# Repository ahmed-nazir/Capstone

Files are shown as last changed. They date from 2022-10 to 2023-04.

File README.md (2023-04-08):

# Formulate

Developer Names: Ahmed Nazir, Stephen Oh, Muhanad Sada, Tioluwalayomi Babayeju

Project Start Date: September 12th 2022

## Description

Competitive engineering extracurricular activities at the University level revolves around the design, build, test, learn (DBTL) cycle. In teams that have not yet reached maturity in completing high quality and timely DBTL cycles, the design/building phases are over-prioritized, leaving the testing/learning phases under-resourced.
Most teams struggling to achieve timely DBTL cycles compete in deeply technical applications of engineering. Problematically, deeply technical applications demand significant amounts of time into the design/build phase of a competition year to create a working prototype.

Our capstone group recognizes the challenge teams face with the under-allocation of resources for testing, and seek to produce a solution that reduces the time to obtain and store quality testing data and extract value from the raw data they collect.

## Summary

https://user-images.githubusercontent.com/31586040/229315702-d01e6bb1-cf8b-4a10-88e6-f17f51ce0d29.mp4

## Device Hardware

https://user-images.githubusercontent.com/31586040/229315661-3c283bd7-a839-4dc5-8188-416b881f1b61.mp4

### Exploded View

Chassis Assembly Exploded View

### PCB
PCB1 

## Folder Structure

The folders and files for this project are as follows:

- docs - Documentation for the project
- refs - Reference material used for the project, including papers
- src - Source code
- test - Testing

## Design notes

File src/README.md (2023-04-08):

# Formulate Source Code

The folders and files for this project are as follows:
- Chassis
- Database
- Desktop Application
- Electrical
- Formulate Application
  - Final Portable Application
- Power Bi

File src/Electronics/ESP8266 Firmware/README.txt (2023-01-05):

The board used in our Formulate project is the ESP8266 12E (NodeMCU 1.0)

- This process is to be done to reset the board to its original state if firmware becomes corrupt

////FLASH FIRMWARE/////

Required:
- NodeMCU Firmware Flasher (https://github.com/nodemcu/nodemcu-flasher)
- Firmware is from (https://github.com/espressif/ESP8266_NONOS_SDK/releases) the version we used was ESP8266_NONOS_SDK v2.0.0

Steps:
- Ensure nothing is connected to the NodeMCU and connect via micro USB

- Go to the advanced tab and set the parameters as follows
	- Baudrate: 230400
	- Flash size: 4MBytes
	- Flash speed: 40MHz
	- SPI Mode: QIO

- Go to the config tab and flash the following files
	- boot_v1.6.bin			@ 0x00000
	- user1.1024.new.2.bin 		@ 0x01000
	- esp_init_data_default.bin	@ 0x3FC000
	- blank.bin				@ 0x7E000

- Open the Arduino IDE and open the serial monitor with the correct COM port and set the baudrate to 115200 and select Newline and CR
	- Send an "AT" command, if it returns "OK" firmware is flashed successfully

	- Set the baudrate to 9600 permanently with "AT+UART_DEF=9600,8,1,0,0"
	
	- Change baudrate to 9600 on the serial monitor and test the "AT" command again after clicking the reset button on the NodeMCU

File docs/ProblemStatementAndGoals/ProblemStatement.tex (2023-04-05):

\documentclass[12pt,titlepage]{article}

\usepackage{tabularx}
\usepackage{booktabs}
\usepackage{float}
\usepackage{fullpage}
\usepackage{longtable}

\title{\huge Problem Statement and Goals\\\progname}

\author{\authname}

\date{\today}

\input{../Comments}
\input{../Common}

\begin{document}

\maketitle
\newpage

\begin{table}[hp]
\caption{Revision History} \label{TblRevisionHistory}
\begin{tabularx}{\textwidth}{llX}
\toprule
\textbf{Date} & \textbf{Developer(s)} & \textbf{Change}\\
\midrule
09/24/22 & Ahmed Nazir & Goals, Stretch Goals\\
09/25/22 & Stephen Oh & Problem Statement, Input/Output, Stakeholders\\
04/03/23 & Stephen, Ahmed & Final Revision\\
04/05/23 & All & Revision 1\\
\bottomrule
\end{tabularx}
\end{table}

\newpage
\tableofcontents
\listoftables

\newpage
\section{Problem Statement}

\wss{You should check your problem statement with the
\href{https://github.com/smiths/capTemplate/blob/main/docs/Checklists/ProbState-Checklist.pdf}
{problem statement checklist}.}
\wss{You can change the section headings, as long as you include the required information.}
%Stephen updated this section, Sunday afternoon
Competitive engineering extracurricular activities at the University level revolve around the design, build,
test, learn (DBTL) cycle. In teams that have not yet reached maturity in completing high quality and
timely DBTL cycles, inexperience in the testing phase causes undesirable inefficiencies in testing
workflow such as unstandardized testing styles, collection of data, and storage of data. Such
inefficiencies also affect team workflow performance at the macro scale due to a reduced ability to
clearly view aggregate trends from unstandardized testing workflows. 

\subsection{Problem}

Our capstone group recognizes the challenge teams face with the under-allocation of resources for testing, and seek to produce a solution that reduces the time to obtain and store quality testing data and extract value from the raw data they collect. \\ 

\subsection{Inputs and Outputs}

\wss{Characterize the problem in terms of ``high level'' inputs and outputs.  
Use abstraction so that you can avoid details.}
%Stephen updated this section, Sunday afternoon

The solution will collect raw data as input and output Key Performance Indicators (KPI) statistics generated from test data. \\

Raw data input to the system will normally be aggregated upon completion of the test. The system will then communicate the contents of the aggregated data to a computing device. Users will have the opportunity to provide input on the raw data collected before saving it to a database. This input should allow the user to add contextual details to the test data to describe what the test is doing. The user will then submit the data to a database with additional information to specify key details of the test. A visualization platform will then allow users to view generated KPI statistics on the test data stored in the database. \\

Inputs: \\
A. User login to link test data to team member. \\
B. Raw data collected by testing sensors. \\
C. Communication method mode selection between wired versus wireless transfer of raw test data between the hardware and the desktop application. \\
%C. User modifications of raw test data file to maintain consistency in data through data point modifications. \\
D. User notes and picture on test data file to specify contextual details of test data collected. 

\newpage
%E. Data processing mode select between generating KPI metrics in real time, live data collection, versus generating KPI metrics in post with data from a complete test. \\

Outputs: \\
A. Tabular view of most recently collected test data over the test duration time on user application upon test completion. \\
B. Test data storage in the database. \\
C. Graphical view on visualization platform of test data over time. \\
D. Tabular view on visualization platform of Key Performance Indicators. \\
E. Visual indication from electrical hardware conveying device on/off state and wireless connection state. 
%C. Historical trends of related test Key Performance Indicator results. \\
%D. Testing trends across sub-teams. \newpage

\subsection{Stakeholders}

Formula Electric teams exemplify a highly technical, extra-curricular engineering team at the University level. On a yearly basis, these teams participate in competitions organized by a governing body, Formula SAE, who judge the quality and effectiveness of engineering ideas, designs, fabrications, and tests applied on a team's vehicle. \\

Specifically, ideal candidates who can benefit from our capstone will be Formula Electric teams with 0-4 years of competition experience. Teams without four years of experience are ideal because they typically cannot finish comprehensive tests to validate sub-team designs and overall vehicle design in a competition year. \\

As a result, our primary stakeholder will be McMaster's Formula Electric team because the team has 3 years of competition experience and faces difficulty validating all aspects of the vehicle through comprehensive testing. \\

\subsection{Environment}
The editing environment for the Arduino will be the Arduino Software IDE which has a text editor for writing code, a serial monitor to receive messages, a toolbar for common functions, and multiple menus for various applications. In this environment, the Arduino can be programmed to communicate with the user interface application running in parallel. \\

Our main environment for software programming will be Visual Studio Code. This is where we will write our code to run functions that will program our Arduino and other functions that we will need. It will also be used to write SQL code which can continually receive data from our hardware components.

\wss{Hardware and software}
\newpage
\section{Goals}
    \begin{longtable}{|p{6cm}|p{10cm}|}
    \hline
    \multicolumn{1}{|c|}{\textbf{Goals}} & \multicolumn{1}{c|}{\textbf{Explanation}} 
    \\ \hline
    Electrical Hardware capable of collecting sensor test data
    & The electrical hardware should be able to obtain and record sensor test data for the main measurements desired. The hardware should be able to collect vibration, shock, temperature and humidity measurements
    \newline                                
    \\ \hline
    Wired and wireless hardware to laptop connection
    & The hardware can support user selection between connection via a wired connection between the hardware to a laptop running the application or a wireless connection between the hardware and the laptop
    \newline                                
    \\ \hline
    Wireless connection failsafe test data storage
    & Electrical Hardware can save a complete data set from the previous test in a local memory module
    \newline                                
    \\ \hline
    Electrical connection mechanism between the electrical hardware and sensor conductors
    & The electrical hardware allows the user to fasten and unfasten sensor conductors to support varying test setups
    \newline                                
    \\ \hline
    A user interface which interacts and submits the data                                 
    & A modern GUI that is intuitive and easy to use, which should be able to communicate with our hardware to receive the measurements from the sensor. The GUI should have two modes, the first showing the live data as it comes from the device. The second mode should allow for the user to preview the data from the test, and extract certain important parts before sending it into the database  
    \newline                                
    \\ \hline
    A record of the historical data should be organized                                
    & To keep testing consistent and comparable, all previous test data should be organized into a database which cannot be edited to prevent users from tampering with test results. Historical data will allow Formula teams to be able to see how certain modifications to their design can improve or hurt motor test results. 
    \newline                                
    \\ \hline
    The final product should have a website which displays the data in a useful manner                                
    & Once all the  tests are sent to the database, we will have a website which shows all the major test information in a data analytics platform to quickly and easily see if the vehicle is hitting targets  
    \newline                              
    \\ \hline
    Setup of our device should be quick and easy                               
    & When a user would like to conduct a test our hardware should be hassle free and not add too much time to the overall setup
    \newline                            
    \\ \hline
    \caption{Goals}
    \end{longtable}

\section{Stretch Goals}
    \begin{longtable}{|p{6cm}|p{10cm}|}
        
        \hline
        \multicolumn{1}{|c|}{\textbf{Goals}} & \multicolumn{1}{c|}{\textbf{Explanation}} 
        \\ \hline
        Custom Website
        &  Creating a GUI from scratch would make the website more customizable to our particular application in terms of UI/UX   
        \newline                              
        \\ \hline
        Critical Alert                              
        & The critical alert feature would display to the user on both the App GUI and on the screen that the current test being performed is exceeding the operating conditions of the device being tested. This will bring attention to the user and they will be able to stop the test
        \newline
        \\ \hline
        Predictive Data                              
        & Since all the testing data and test conditions are being stored in our database, we could create a machine learning model which will be able to tell us how the motor will perform under certain conditions                         
        \newline       
        \\ \hline
        Security                              
        & When data is being transmitted from our hardware device to our computer, the data should be encrypted and secure to prevent tampering with data
        \newline                           
        \\ 
        \hline
        \caption{Stretch Goals}
    \end{longtable}

\end{document}

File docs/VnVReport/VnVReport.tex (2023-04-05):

\documentclass[12pt, titlepage]{article}

\usepackage{booktabs}
\usepackage{tabularx}
\usepackage{hyperref}

\usepackage{fullpage}
\usepackage[round]{natbib}
\usepackage{multirow}
\usepackage{booktabs}
\usepackage{tabularx}
\usepackage{graphicx}
\usepackage{float}
\usepackage{hyperref}
\usepackage{colortbl}
\usepackage{longtable}
\usepackage[table]{xcolor} 
\usepackage{longtable}
\hypersetup{
    colorlinks,
    citecolor=black,
    filecolor=black,
    linkcolor=red,
    urlcolor=blue
}
\usepackage[round]{natbib}

\input{../Comments}
\input{../Common}

\begin{document}

\title{\huge Verification and Validation Report \\ \progname} 
\author{\authname}
\date{\today}
	
\maketitle

\pagenumbering{roman}

\section{Revision History}

\begin{tabularx}{\textwidth}{p{3cm}p{2cm}X}
\toprule {\bf Date} & {\bf Version} & {\bf Notes}\\
\midrule
March 3, 2023 & 1.0 & Final Revision\\
\bottomrule
\end{tabularx}

~\newpage

\section{Symbols, Abbreviations and Acronyms}

\renewcommand{\arraystretch}{1.2}
\begin{tabular}{l l} 
  \toprule		
  \textbf{symbol} & \textbf{description}\\
  \midrule 
  \progname & Mechatronics Engineering Capstone Course\\
  UART & Universal Asynchronous Receiver-Transmitter\\
  SPI & Serial Peripheral Interface\\
  I2C & Inter-Integrated Circuit\\
  USB & Universal Serial Bus\\
  TCP & Transmission Control Protocol\\
  IP & Internet Protocol\\
  SPDT & Single pole, double throw \\
  TCP/IP & Transmission Control Protocol / Internet Protocol \\
  SOC & Software On Chip \\
  SPST & Single pole, single throw \\
  TX & Transmit \\
  RX & Recieve \\
  USB & Universal Serial Bus \\
  LED & Light-emitting diode \\
  GB & GigaByte \\
  SD & Secure Digital \\
  PCB & Printed Circuit Board \\
  \bottomrule
\end{tabular}\\

\wss{symbols, abbreviations or acronyms -- you can reference the SRS tables if needed}

\newpage

\tableofcontents

\listoftables %if appropriate

\listoffigures %if appropriate

\newpage

\pagenumbering{arabic}

\section{Functional Requirements Evaluation}
\subsection{Sensor Verification}
%sensor validation: Stephen
\begin{table}[H]
  \begin{tabular}{| p{0.15\textwidth} | p{0.10\textwidth}| p{0.28\textwidth}| p{0.28\textwidth}| p{0.09\textwidth}|}
    \hline
    \rowcolor[gray]{0.9}
    Test Number & Type & Input & Output & Result\\
    \hline
    ST-SV 1 & Manual & Room at a constant 25 $^{\circ}$C ambient & Constant 25.4 $^{\circ}$C reading from temperature sensor & Pass \\
    \hline
    ST-SV 2 & Manual & Room at constant 40\% humidity $^{\circ}$C & Constant 43\% reading from humidity sensor & Pass \\
    \hline
    ST-SV 3 & Manual & 4 seperate phonecalls with accelerometer measuring haptic feedback & Maximum error between acceleration profiles of phone calls within 0.2 meters per second squared & Pass  \\
    \hline
  \end{tabular}
  \caption{Sensor Validation}
  \end{table}

%device telemetry: Ahmed
\subsection{Device Telemetry}
\begin{table}[H]
  \begin{tabular}{| p{0.15\textwidth} | p{0.10\textwidth}| p{0.28\textwidth}| p{0.28\textwidth}| p{0.09\textwidth}|}
    \hline
    \rowcolor[gray]{0.9}
    Test Number & Type & Input & Output & Result\\
    \hline
    ST-DT 1 & Manual & The device is connected via Wi-Fi and the start button is pressed on the GUI & The device beings to send and display the sensor data in the GUI & Pass \\
    \hline
    ST-DT 2 & Manual & The device is connected via Wi-Fi and the start button is pressed multiple times in the GUI & The start button greys out not allowing the user to press it multiple times and the sensors still send data to the GUI & Pass \\
    \hline
    ST-DT 3 & Manual & The device is connected via Wi-Fi and the stop button is pressed on the GUI & The device stops sending data to the GUI & Pass  \\
    \hline
    ST-DT 4 & Manual & The device is connected via Wi-Fi and the stop button is pressed multiple times in the GUI & The stop button greys out not allowing the user to press it multiple times and the device does not send data & Pass  \\
    \hline
  \end{tabular}
  \caption{Device Telemetry}
  \end{table}

%device hardware: Stephen
\subsection{Device Hardware}
\begin{table}[H]
  \begin{tabular}{| p{0.15\textwidth} | p{0.10\textwidth}| p{0.28\textwidth}| p{0.28\textwidth}| p{0.09\textwidth}|}
    \hline
    \rowcolor[gray]{0.9}
    Test Number & Type & Input & Output & Result\\
    \hline
    ST-DH 1 & Manual & Temperature sensor male end JST connector unconnected to the device's female JST connector & Device measured the room's ambient temperature at 23.4 $^{\circ}$C & Pass \\
    \hline
    ST-DH 2 & Manual & Device collecting sensor data at low battery charge & Device unoperational upon battery depletion and halted sensor data collection & Fail \\
    \hline
    ST-DH 3 & Manual & 5 kg dumbbell placed on each corner of the device chassis & No plastic failure in device chassis & Pass  \\
    \hline
    ST-DH 4 & Manual & A member on the formula electric team was given a cross screwdriver, M4 screw, the device, and DIN rail & The formula electric team member mounted the device in 40 seconds & Pass  \\
    \hline
%REMEMBER TO DELETE ST-DH5 FROM VNVPLAN, WE DO NOT NEED THIS TEST AS WE DO NOT HAVE A SCREEN OR DEVICE STATUS MEASUREMENTS
  \end{tabular}
  \caption{Device Hardware}
  \end{table} 

  ST-DH3 failed the functional test case. The team estimated the time required to design and integrate a rechargeable battery subsystem within the project's timeline was 1.5 weeks and decided the effort was not worthwhile relative to other project objectives. As a result, the failure of this test case lead the expected operation at low battery to be adjusted. Users are now expected to replace the battery on a regular schedule to prevent a failure in test integrity due to charge depletion. \\

\newpage
%desktop app: Mo
\subsection{Desktop Application}
ST-DA3 and ST-DA4 are included in unit testing, refer to section 5.3 for further details.
\begin{table}[H]
\begin{tabular}{| p{0.15\textwidth} | p{0.10\textwidth}| p{0.28\textwidth}| p{0.28\textwidth}| p{0.09\textwidth}|}
  \hline
  \rowcolor[gray]{0.9}
  Test Number & Input & Expected Output & Actual Output & Result\\
  \hline
  ST-DA5 & User clicks on 'Start Test' button in 'View Test' page & Live data start to populate a table in the UI & Live measurement data is displayed in a table in the UI & pass \\
  \hline
\end{tabular}
\caption{Desktop Application}
\end{table}

%data analytics: Tio
\subsection{Data Dashboard}
\begin{table}[H]
  \begin{tabular}{| p{0.15\textwidth} | p{0.10\textwidth}| p{0.28\textwidth}| p{0.28\textwidth}| p{0.09\textwidth}|}
    \hline
    \rowcolor[gray]{0.9}
    Test Number & Type & Input & Output & Result\\
    \hline
    ST-DD 1 & Manual & The user was given a username and password to login into Power BI & The user was able to view all the different data that was being recorded during the test and previous tests as well & Pass\\
    \hline
    ST-DD 2 & Manual & The user was given a fake username and password that is not authorized to view the data & The user was not able to view the Power BI dataset that was created to view all the different test data & Pass\\
    \hline
  \end{tabular}
  \caption{Data Analytics}
  \end{table} 

We created our Data Dashboard through a visualization tool called Power Bi and tested it to see if we were able to connect to the database which contained all our data values. We able to get all the values of our data from the database since Power Bi has a method that can connect to database that authorized users are allowed to connect to. Since this was the case we were able to pass this this requirement for our the data analytics.

%database: Mo
\subsection{Database}
\begin{table}[H]
\begin{tabular}{| p{0.15\textwidth} | p{0.10\textwidth}| p{0.28\textwidth}| p{0.28\textwidth}| p{0.09\textwidth}|}
  \hline
  \rowcolor[gray]{0.9}
  Test Number & Input & Expected Output & Actual Output & Result\\
  \hline
  ST-D1 & User clicks on 'Submit' button in 'Submit Test' page consecutively in a short period of time & UI displays error message 'Too many submissions' in red & 'Too many submissions' is displayed in red & pass \\
  \hline
\end{tabular}
\caption{Database}
\end{table}

\newpage

\section{Nonfunctional Requirements Evaluation}
\subsection{Usability}
%Stephen
%Need a graph (that we generate) that supports data

  \begin{longtable}{| p{0.15\textwidth} | p{0.10\textwidth}| p{0.28\textwidth}| p{0.28\textwidth}| p{0.09\textwidth}|}
    \hline
    \rowcolor[gray]{0.9}
    Test Number & Type & Input & Output & Result\\
    \hline
    ST-U 1-A & Manual & User connects a thermistor to device, begins collecting sensor test data and gathers data for 1 minute, completes collecting sensor test data, adds remarks to the test, and submits test data to database & User completed the overall process in 3 minutes 43 seconds and rated the sensor mount and measuring procedure a 5. All other categories were given a 4 & Pass \\
    \hline
    ST-U 1-B & Manual & User adjusts Arduino code for a fluid flow rate sensor, connects the sensor to the device, begins collecting sensor test data and gathers data for 1 minute, completes collecting sensor test data, adds remarks to the test, and submits test data to database & User completed the process in 49 minutes 15 seconds and rated the overall experience a 2. The sensor mount and measuring procedure categories were given a 5. All other cattegories were given a 4 & Fail \\
    \hline
    ST-U 2-A & Manual & Device collecting sensor data with wired connection to a laptop running the python application & Python application GUI displayed at minimal latency. Less than 1 second latency for changes in sensor measurements to display on GUI. Users selected Formulate for all 4 categories & Pass \\
    \hline
    ST-U 2-B & Manual & Device collecting sensor data with wireless connection to a laptop running the python application & Python application GUI displayed at minimal latency. Less than 1 second latency for changes in sensor measurements to display on GUI. Users selected Formulate for all 4 categories& Pass \\
    \hline

    ST-U 3-A & Manual & Device connection to application is broken. User submits previous test data held on the micro-SD module to the database & Test data submits and test contents can be viewed on dashboard. An average score of 4 was provided & Pass \\
    \hline
    ST-U 3-B & Manual & Application connection to database is broken. User can connect a temperature sensor, start a test, and stop a test & Device recognizes sensor, starts test, and stops test. An average score of 4 was provided & Pass  \\
    \hline
    \caption{Usability}

  \end{longtable}

  \begin{figure}[htbp!]
    \begin{center}
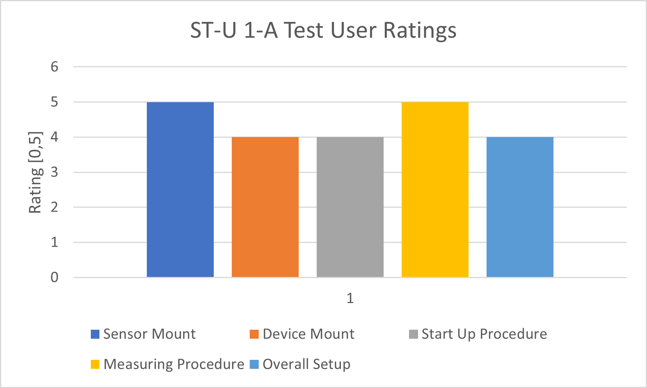
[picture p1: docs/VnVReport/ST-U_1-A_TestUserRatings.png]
    
    \caption{ST-U 1-A Test User Ratings}
    \end{center}
    \end{figure}

  \begin{figure}[htbp!]
    \begin{center}
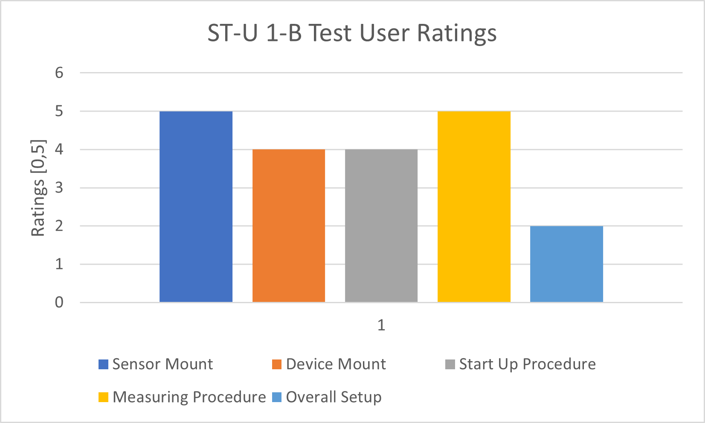
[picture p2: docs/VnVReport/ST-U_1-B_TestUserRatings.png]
    
    \caption{ST-U 1-B Test User Ratings}
    \end{center}
    \end{figure}
\newpage
  ST-U 1-B failed the usability test case. The difference between ST-U 1-B and ST-U 1-A was the user requirement to adjust and write the Arduino code for a sensor not previously used with the device. Notably, the user experienced difficulty and was intimidated with adjusting existing code to integrate a new sensor. This effect was shown in both the increased time to complete the overall process and the decreased rating in the overall test experience category. As a result, the project will have an approach whereby the user should only interact with the graphical user interface to reduce the user's feelings of complexity and intimidation when integrating a new sensor. The goal is to abstract the adjustments in the backend when implementing a new sensor by having the user interact only with the GUI and following guided steps in plain English to fill in the required information to integrate a new sensor. \\

\subsection{Performance}
%Tio
\begin{table}[H]
  \begin{tabular}{| p{0.15\textwidth} | p{0.10\textwidth}| p{0.28\textwidth}| p{0.28\textwidth}| p{0.09\textwidth}|}
    \hline
    \rowcolor[gray]{0.9}
    Test Number & Type & Input & Output & Result\\
    \hline
    ST-P 1 & Dynamic, Manual & The device will be mounted and be tested in various conditions & The device was operational and stayed physcially intact after being tested in various conditions & Pass\\
    \hline
    ST-P 2 & Dynamic, Manual & The device will be operating and collecting data from a test and streaming the results to our desktop application & The latency between the collecting of data and the streaming of it remained below 10 seconds & Pass\\
    \hline
    ST-P 3 & Dynamic, Manual & The device will be operating with one or more of the connections to either the device, application and or database & The user is still able to obtain the test results of the current test no matter which connections are missing on the overall connection & Pass\\
    \hline
  \end{tabular}
  \caption{Performance}
  \end{table}

  \begin{figure}[H]
    \begin{center}
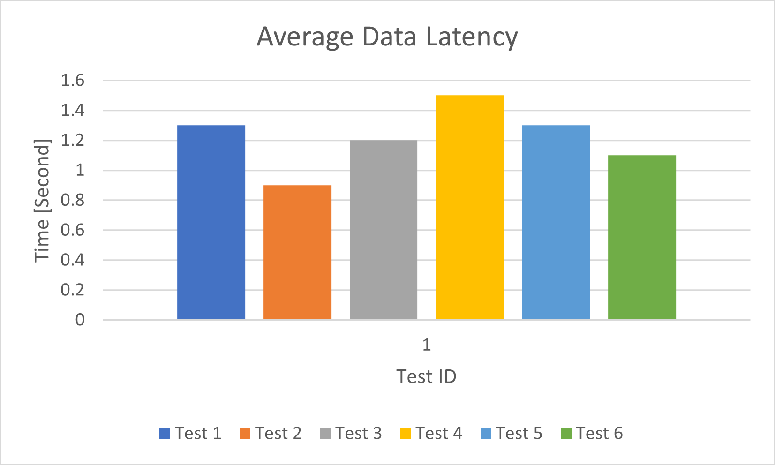
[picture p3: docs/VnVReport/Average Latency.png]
    
    \caption{Average Latency Results of Each Test}
    \end{center}
    \end{figure}

\subsection{Security}
%Tio
\begin{table}[H]
  \begin{tabular}{| p{0.15\textwidth} | p{0.10\textwidth}| p{0.28\textwidth}| p{0.28\textwidth}| p{0.09\textwidth}|}
    \hline
    \rowcolor[gray]{0.9}
    Test Number & Type & Input & Output & Result\\
    \hline
    ST-S 1 & Dynamic, Manual & User will receive numerous usernames and passwords and attempt to access the database & The database was only accessible using the correct username, password and only with specific ip addresses that have been accepted & Pass\\
    \hline
    ST-S 2 & Dynamic, Manual & Multiple fake data points were attempted to be added to the database & The database remained the same even after the attempted modification ensuring that only authorized were allowed to modify the database & Pass\\
    \hline
  \end{tabular}
  \caption{Security}
  \end{table}

\newpage
\section{Unit Testing}
\subsection{Module - ui\_functions.py}
%Desktop App Code: Mo
%Arduino Code: Ahmed
connect\_wireless(self) - Tested by clicking connect button on wireless page
\begin{table}[H]
  \begin{tabular}{| p{0.1\textwidth} | p{0.15\textwidth}| p{0.28\textwidth}| p{0.28\textwidth}| p{0.09\textwidth}|}
    \hline
    \rowcolor[gray]{0.9}
    Test No. & Input & Expected Output & Actual Output & Result\\
    \hline
    U1 & Connected to Formulate Wi-Fi & The application should connect to the device and display that it is connected & The application shows that the device is connected & Pass \\
    \hline
    U2 & Not Connected to Formulate Wi-Fi  & The application should display a pop up error indicating to the user that they need to connect to the Formulate Wi-Fi & A popup is displayed to the user to indicate they need to connect to Wi-Fi & Pass \\
    \hline
    U3 & -Connected to Formulate Wi-Fi -Device is connected via Serial (Wired) & The application should disconnect from serial and follow U1 & The application disconnects from serial and follows U1 & Pass \\
    \hline
  \end{tabular}
  \caption{Unit Test - connect\_wireless(self)}
  \end{table}

disconnect\_wireless(self) - Tested by clicking disconnect button on wireless page
\begin{table}[H]
  \begin{tabular}{| p{0.1\textwidth} | p{0.15\textwidth}| p{0.28\textwidth}| p{0.28\textwidth}| p{0.09\textwidth}|}
    \hline
    \rowcolor[gray]{0.9}
    Test No. & Input & Expected Output & Actual Output & Result\\
    \hline
    U4 & -Connected to Formulate Wi-Fi -The disconnect button is clicked & The application should disconnect from the board and display that it is disconnected & The application disconnects from board and shows its disconnected & Pass \\
    \hline
    U5 & Not Connected to Formulate Wi-Fi  & The application should not display the disconnect button on the connectivity widget & The application does not display the disconnect button & Pass \\
    \hline
  \end{tabular}
  \caption{Unit Test - disconnect\_wireless(self)}
  \end{table}

  connect\_wired(self) - Tested by clicking connect button on wired page
  \begin{table}[H]
    \begin{tabular}{| p{0.1\textwidth} | p{0.15\textwidth}| p{0.28\textwidth}| p{0.28\textwidth}| p{0.09\textwidth}|}
      \hline
      \rowcolor[gray]{0.9}
      Test No. & Input & Expected Output & Actual Output & Result\\
      \hline
      U6 & Connected to PC via USB and the correct COM port is selected in the Wire connectivity widget & The application should connect to the device and display that it is connected & The application shows that the device is connected & Pass \\
      \hline
      U7 & Not Connected to PC via wire  & The application should not display any COM port in the widget & The wired drop down is empty and shows no COM port & Pass \\
      \hline
      U8 & -Connected to PC via USB and the correct COM port is selected in the Wire connectivity widget -Device is connected via WiFi & The application should disconnect from WiFi and follow U6 & The application disconnects from WiFi and follows U6 & Pass \\
      \hline
    \end{tabular}
    \caption{Unit Test - connect\_wired(self)}
    \end{table}
  
  disconnect\_wired(self) - Tested by clicking disconnect button on wired page
  \begin{table}[H]
    \begin{tabular}{| p{0.1\textwidth} | p{0.15\textwidth}| p{0.28\textwidth}| p{0.28\textwidth}| p{0.09\textwidth}|}
      \hline
      \rowcolor[gray]{0.9}
      Test No. & Input & Expected Output & Actual Output & Result\\
      \hline
      U9 & -Connected via wired -The disconnect button is clicked & The application should disconnect from the board and display that it is disconnected & The application disconnects from board and shows its disconnected & Pass \\
      \hline
    \end{tabular}
    \caption{Unit Test - disconnect\_wired(self)}
    \end{table}
\newpage

  ping(self) - Tested by clicking connect button
  \begin{table}[H]
    \begin{tabular}{| p{0.1\textwidth} | p{0.15\textwidth}| p{0.28\textwidth}| p{0.28\textwidth}| p{0.09\textwidth}|}
      \hline
      \rowcolor[gray]{0.9}
      Test No. & Input & Expected Output & Actual Output & Result\\
      \hline
      U10 & Connected via WiFi & The application should read which sensors are flashed on the board and display them & The application gets which sensors are flashed and displays them & Pass \\
      \hline
      U11 & Connected via wired & The application should read which sensors are flashed on the board and display them & The application gets which sensors are flashed and displays them & Pass \\
      \hline
    \end{tabular}
    \caption{Unit Test - ping(self)}
    \end{table}

  startTest(self) - Tested by clicking startTest button
  \begin{table}[H]
    \begin{tabular}{| p{0.1\textwidth} | p{0.15\textwidth}| p{0.28\textwidth}| p{0.28\textwidth}| p{0.09\textwidth}|}
      \hline
      \rowcolor[gray]{0.9}
      Test No. & Input & Expected Output & Actual Output & Result\\
      \hline
      U12 & Connected via WiFi & The application should read data from the bytestring sent from the ESP8266 and display it in the table as the data is coming & The application reads the data and displays it correctly & Pass \\
      \hline
      U13 & Connected via wired & The application should read data from the bytestring sent from the Arduino UNO and display it in the table as the data is coming & The application reads the data and displays it correctly & Pass \\
      \hline
    \end{tabular}
    \caption{Unit Test - startTest(self)}
    \end{table}
\newpage
  stopTest(self) - Tested by clicking stopTest button
  \begin{table}[H]
    \begin{tabular}{| p{0.1\textwidth} | p{0.15\textwidth}| p{0.28\textwidth}| p{0.28\textwidth}| p{0.09\textwidth}|}
      \hline
      \rowcolor[gray]{0.9}
      Test No. & Input & Expected Output & Actual Output & Result\\
      \hline
      U14 & Connected via WiFi & The application should stop reading data sent from the ESP8266  & The application stops reading the data & Pass \\
      \hline
      U15 & Connected via wired & The application should stop reading data sent from the Arduino UNO & The application stops reading the data & Pass \\
      \hline
    \end{tabular}
    \caption{Unit Test - stopTest(self)}
    \end{table}

  declineData(self) - Tested by clicking stopTest button
  \begin{table}[H]
    \begin{tabular}{| p{0.1\textwidth} | p{0.15\textwidth}| p{0.28\textwidth}| p{0.28\textwidth}| p{0.09\textwidth}|}
      \hline
      \rowcolor[gray]{0.9}
      Test No. & Input & Expected Output & Actual Output & Result\\
      \hline
      U16 & There is data populated in the table & The application should clear all the data in the table and display an empty table  & The application clears the data and displays an empty table & Pass \\
      \hline
      U17 & There is no data populated in the table & The application should clear all the data in the table and display an empty table  & The application clears the data and displays an empty table & Pass \\
      \hline
    \end{tabular}
    \caption{Unit Test - declineData(self)}
    \end{table}

    setup\_page(self, page\_name) - Output observed in the UI \newline
\begin{table}[H]
  \begin{tabular}{| p{0.10\textwidth} | p{0.15\textwidth}| p{0.28\textwidth}| p{0.28\textwidth}| p{0.09\textwidth}|}
    \hline
    \rowcolor[gray]{0.9}
    Test No. & Input & Expected Output & Actual Output & Result\\
    \hline
    U18 & 'sign up page' & Sign up page has items added to the ‘team role’ dropdown and password/confirm password fields have hidden entry & Sign up page has items in ‘team role’ dropdown and password fields have the input hidden & pass \\
    \hline
    U19 & 'login page' & Login page’s password field entry is hidden & Login page’s password field entry is hidden & pass \\
    \hline
  \end{tabular}
  \caption{Unit Test - setup\_page}
\end{table}

\newpage
login\_into\_app(self) - Tested by clicking 'Sign In' button in Login page of the UI
\begin{table}[H]
  \begin{tabular}{| p{0.10\textwidth} | p{0.15\textwidth}| p{0.28\textwidth}| p{0.28\textwidth}| p{0.09\textwidth}|}
    \hline
    \rowcolor[gray]{0.9}
    Test No. & Input & Expected Output & Actual Output & Result\\
    \hline
    U20 & Signing in with correct user information and ‘admin’ user  & UI transitions to homepage and username is displayed in the top right corner  & UI transitioned to homepage and ‘admin’ was displayed in the top right corner & pass \\
    \hline
    U21 & Signing in with no password & UI displays error message ‘Please enter a password’ in red color & ‘Please enter a password’ is displayed in red & pass \\
    \hline
    U22 & Signing in with no username & UI displays error message ‘Please enter a username’ in red color & ‘Please enter a password’ is displayed in red & pass \\
    \hline
    U23 & Signing in with non-existing username & UI displays error message ‘User does not exist, try again’ in red color & ‘User does not exist, try again’ is displayed in red & pass \\
    \hline
    U24 & Signing in with incorrect password & UI displays error message ‘Incorrect password, try again’ in red color & ‘Incorrect password, try again’, is displayed in red & pass \\
    \hline
  \end{tabular}
  \caption{Unit Test - login\_into\_app}
\end{table}

\newpage
continue\_signup(self) - Tested by clicking 'Continue' button in Sign Up page of the UI 
\begin{table}[H]
  \begin{tabular}{| p{0.10\textwidth} | p{0.15\textwidth}| p{0.28\textwidth}| p{0.28\textwidth}| p{0.09\textwidth}|}
    \hline
    \rowcolor[gray]{0.9}
    Test No. & Input & Expected Output & Actual Output & Result\\
    \hline
    U25 & Valid account registration information & UI transitions to homepage and new rows are added to Users and Login tables in database & UI transitioned to homepage and new rows with user information and hashed passwords were added to Users and Login tables in database & Pass \\
    \hline
    U26 & At least one field is missing input & UI displays error message ‘Please fill in missing fields’ in red color & ‘Please fill in missing fields’ is displayed in red & Pass \\
    \hline
    U27 & Username is less than 4 characters & UI displays error message ‘Username requires at least 4 characters’ in red color & ‘Username requires at least 4 characters’ is displayed in red & Pass \\
    \hline
    U28 & Password is less than 8 characters & UI displays error message ‘Password requires at least 8 characters’ in red color & ‘Password requires at least 8 characters’ is displayed in red & Pass \\
    \hline
    U29 & Password does not have a number & UI displays error message ‘Password requires at least one number’ in red color & ‘Password requires at least one number’ is displayed in red & Pass \\
    \hline
    U30 & Password does not contain a letter & UI displays error message ‘Password requires at least one alphabet’ in red color & ‘Password requires at least one alphabet’ is displayed in red & Pass \\
    \hline
    U31 & Password does not contain a non-alphanumeric character & UI displays error message ‘Password requires at least one non-alphanumeric character’ in red color & Correct error message is displayed but is cut off & Fail \\
    \hline
    U32 & Password and Confirm Password fields do not match & UI displays error message ‘Passwords do not match’ in red color & ‘Passwords do not match’ is displayed in red & Pass \\
    \hline
  \end{tabular}
  \caption{Unit Test - continue\_signup}
\end{table}

move\_to\_submit\_test(self): Tested by clicking on ‘Submit’ button in View Test page
\begin{table}[H]
  \begin{tabular}{| p{0.10\textwidth} | p{0.15\textwidth}| p{0.28\textwidth}| p{0.28\textwidth}| p{0.09\textwidth}|}
    \hline
    \rowcolor[gray]{0.9}
    Test No. & Input & Expected Output & Actual Output & Result\\
    \hline
    U33 & Clicking on button while logged in & UI transitions to Submit Test page & UI transitioned to Submit Test page & Pass \\
    \hline
    U34 & Clicking on button while not signed in & UI displays error message ‘Please login to submit tests’ & ‘Please login to submit tests’ is displayed & Pass \\
    \hline
  \end{tabular}
  \caption{Unit Test - move\_to\_submit\_test}
\end{table}

browse\_and\_display\_pictures(self) - Tested by clicking on Upload Image button in Submit Test page  
\begin{table}[H]
  \begin{tabular}{| p{0.10\textwidth} | p{0.15\textwidth}| p{0.28\textwidth}| p{0.28\textwidth}| p{0.09\textwidth}|}
    \hline
    \rowcolor[gray]{0.9}
    Test No. & Input & Expected Output & Actual Output & Result\\
    \hline
    U35 & Described above & File explorer window pops up, user can select an image, and selected image is displayed in UI & The same as expected output & Pass \\
    \hline
  \end{tabular}
  \caption{Unit Test - browse\_and\_display\_pictures}
\end{table}

upload\_test\_info(self) - Tested by clicking on 'Submit' button in Submit Test page 
\begin{table}[H]
  \begin{tabular}{| p{0.10\textwidth} | p{0.15\textwidth}| p{0.28\textwidth}| p{0.28\textwidth}| p{0.09\textwidth}|}
    \hline
    \rowcolor[gray]{0.9}
    Test No. & Input & Expected Output & Actual Output & Result\\
    \hline
    U36 & Valid data and test information provided & UI transitions to homepage and new test information should be visible in PowerBi dashboard & New test information was visibile in PowerBi dashboard & Pass \\
    \hline
    U37 & No test data & UI displays popup with error message 'No data to submit' & 'No data to submit' error popup was displayed & Pass \\
    \hline
    U38 & Valid test data but missing test name and/or purpose & UI displays popup with the error message 'Fill in missing fields' & 'Fill in missing fields' error popup was displayed & Pass \\
    \hline
  \end{tabular}
  \caption{Unit Test - upload\_test\_info}
\end{table}

\subsection{Module - mainArduino.ino}\begin{table}[H]
  \begin{tabular}{| p{0.10\textwidth} | p{0.15\textwidth}| p{0.28\textwidth}| p{0.28\textwidth}| p{0.09\textwidth}|}
    \hline
    \rowcolor[gray]{0.9}
    Test No. & Input & Expected Output & Actual Output & Result\\
    \hline
    U39 & Device is connected via Wired and temperature sensor is connected & A bytestring of data in the form of (A1XX) should display & A bytestring of the correct form is displayed on the Arduino serial monitor & Pass \\
    \hline
    U40 & Device is connected via WiFi and temperature sensor is connected & A bytestring of data in the form of (A1XX) should display & A bytestring of the correct form is displayed on the Arduino serial monitor & Pass \\
    \hline
  \end{tabular}
  \caption{Unit Test - Arduino Bytestring}
\end{table}

\subsection{Module - mainESP8266.ino}\begin{table}[H]
  \begin{tabular}{| p{0.10\textwidth} | p{0.15\textwidth}| p{0.28\textwidth}| p{0.28\textwidth}| p{0.09\textwidth}|}
    \hline
    \rowcolor[gray]{0.9}
    Test No. & Input & Expected Output & Actual Output & Result\\
    \hline
    U41 & Device is connected to the Formulate WiFi & A Green LED should turn on & Green LED is turned on & Pass \\
    \hline
    U42 & Device is connected to Formulate WiFi and data is being transferred & An orange LED should turn on & A Orange LED is turned on & Pass \\
    \hline
  \end{tabular}
  \caption{Unit Test - ESP8266 Wireless Test}
\end{table}

\newpage
\section{Changes Due to Testing}
%Each person will have to write a section here. Each FR and NFR will have a paragraph here, so based on what was assigned earlier, we will need to write a section here.

\subsection{Functional Requirements}
%NOTE: Only keep requirements in here that were changed
%FR 1 :
%Point 1: Changes
%Point 2: Effect the change had on project
FR 11 was changed such that the battery under expected operational use is non-rechargeable. Batteries will continue to be used but will change from rechargeable to non-rechargeable batteries with a scheduled replacement timeline close to charge depletion. This change followed the test ST-DH 2 results. \\

\subsection{Nonfunctional Requirements}

\wss{This section should highlight how feedback from the users and from 
the supervisor (when one exists) shaped the final product.  In particular 
the feedback from the Rev 0 demo to the supervisor (or to potential users) 
should be highlighted.}

Additional considerations to the GUI must be made in response to NFR1,  NFR2, and the test result ST-U 1-B. In particular, the team plans to improve the GUI to improve the user experience by minimizing and ultimately eliminating interaction with Arduino code when integrating new sensors and making the user work with the GUI to integrate new sensors. \\
		
\subsection{Unit Testing}
There was only one failed unit test case which was U31. The test case failed because the correct error message was being displayed but, it was cut off meaning only a portion of the error message was visible. In order to fix this, the size of the UI text window for the error message was increased and the result was that the UI now correctly displays the full message.

\section{Trace to Requirements}
%VnV Plan has this table
\begin{tabular}{| p{0.45\textwidth} | p{0.45\textwidth}|}
  \hline
  \rowcolor[gray]{0.9}
  Requirement & Test \\
  \hline
  FR 1 & ST-SV 1, ST-SV 2, ST-SV 3 \\
  \hline
  FR 2 & ST-DT 1, ST-DT 2, ST-DT 3, ST-DT 4 \\
  \hline
  FR 3 & ST-DT 1, ST-DT 2 \\
  \hline
  FR 4 & ST-DT 3, ST-DT 4 \\
  \hline
  FR 5 & ST-SV 1, ST-SV 2, ST-SV 3 \\
  \hline
  FR 6 & ST-DA 1 \\
  \hline
  FR 7 & ST-DA 3, ST-DA 4 \\
  \hline
  FR 8 & ST-DD 1 \\
  \hline
  FR 9 & ST-DH 3 \\
  \hline
  FR 10 & ST-DH 4 \\
  \hline
  FR 11 & ST-DH 2 \\
  \hline
  FR 12 & ST-DT 1, ST-DT 2, ST-DT 3, ST-DT 4 \\
  \hline
  FR 13 & ST-DH 4 \\
  \hline
  FR 14 & ST-DA 5 \\
  \hline
  FR 15 & ST-DH 1, ST-DA 5\\
  \hline
  FR 16 & ST-DD 2 \\
  \hline
  FR 17 & ST-DD 1 \\
  \hline
  FR 18 & ST-DA 3 \\
  \hline
  NFR 1 & ST-U 1-A, ST-U 1-B \\
  \hline
  NFR 2 & ST-U 2-A, ST-U 2-B, ST-U 3-A, ST-U 3-B \\
  \hline
  NFR 3 & ST-P 2 \\
  \hline
  NFR 4 & ST-P 1, ST-P 3 \\
  \hline
  NFR 5 & ST-U 2-A, ST-U 2-B \\
  \hline
  NFR 6 & ST-P 1 \\
  \hline
  NFR 7 & ST-P 3 \\
  \hline
  NFR 8 & ST-U 2-A, ST-U 2-B \\
  \hline
  NFR 9 & ST-S 1, ST-S 2 \\
  \hline
\end{tabular}

\newpage
\section*{Appendix --- Reflection}

\wss{The information in this section will be used to evaluate the team members on the
graduate attribute of Reflection.  Please answer the following question:

  In what ways was the Verification and Validation (VnV) Plan different
  from the activities that were actually conducted for VnV?  If there were
  differences, what changes required the modification in the plan?  Why did
  these changes occur?  Would you be able to anticipate these changes in future
  projects?  If there weren't any differences, how was your team able to clearly
  predict a feasible amount of effort and the right tasks needed to build the
  evidence that demonstrates the required quality?  (It is expected that most
  teams will have had to deviate from their original VnV Plan.)}

 %Tio
  In our Verification and Validation Plan we had planned to create a website containing all the information and test data received throughout various tests by Mac Formula Electric. The website will organize data and help the user analyze it as well. We ultimately decided to use Power Bi, which is an interactive data visualization software that all McMaster students can access. We used Power Bi to meet our data visualization requirements as it helped improved user ease of use and compatibility with the database where our test data was being stored. We were able to verify that using Power Bi worked for our data analytics portion because the members of the Mac Formula Electric were able to use the visualized test data to aid them in future designs.\\

 %Stephen  
 The Verification and Validation Plan for usability differed from the actual activities conducted in the VnV. For example, the usability test ST-U 1 did not originally account for sensor code integration by the user during the test. But during VnV, the team realized that we needed to know both the total process time taken when the user already had the required code and when the user had to integrate the code to adequately determine the project's ability to meet the FR's and NFR's defined in the SRS. In the future, prototyping earlier in the design process can help identify important test cases when generating the VnV Plan. \\  %End of paragraph

 %Ahmed  
 For the most part, our VnV plan the physical device and embedded code was closely aligned with the actual VnV activities we conducted. During the VnV planning session, our team worked diligently to clearly outline the specific objectives and requirements for our final product. We conducted extensive research, and actively engaged with Formula Electric team members to gain a deeper understanding of the type of device they were looking for. This helped us develop a comprehensive VnV plan that was tailored to the specific needs and expectations of the project. While there were some changes to the plan as we progressed, the core elements were largely unchanged. This was due to a thorough planning process and our ability to anticipate potential challenges or modifications that might arise over the course of the project. Ultimately, this allowed us to execute our VnV activities with precision and confidence, and to demonstrate the high level of quality that was required for the final product. \\

  %Mo 
  After unit, desktop application, and database testing, the GUI verification activities were different from the plan in a variety of ways. Firstly, there was no unit testing in the plan because it was too early in the project to determine modules and units therefore, most test cases for unit testing were new. Secondly, some desktop application and database system tests mentioned in the plan were not applicable because some features were changed or not added. During UI implementation, it was possible to anticipate those changes in future projects but it would depend on the nature of the project. In this case, the project's UI was modified greatly from initial design to implementation. However, since some backend features of the project changed, it is completely normal for the verification to be also modified to accommodate the new or edited features of the UI.

\end{document}

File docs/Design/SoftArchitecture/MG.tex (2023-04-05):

\documentclass[12pt, titlepage]{article}

\usepackage{fullpage}
\usepackage[round]{natbib}
\usepackage{multirow}
\usepackage{booktabs}
\usepackage{tabularx}
\usepackage{graphicx}
\usepackage{float}
\usepackage{hyperref}
\hypersetup{
    colorlinks,
    citecolor=blue,
    filecolor=black,
    linkcolor=red,
    urlcolor=blue
}

\input{../../Comments}
\input{../../Common}

\newcounter{acnum}
\newcommand{\actheacnum}{AC\theacnum}
\newcommand{\acref}[1]{AC\ref{#1}}

\newcounter{ucnum}
\newcommand{\uctheucnum}{UC\theucnum}
\newcommand{\uref}[1]{UC\ref{#1}}

\newcounter{mnum}
\newcommand{\mthemnum}{M\themnum}
\newcommand{\mref}[1]{M\ref{#1}}

\begin{document}

\title{\huge Module Guide \\\progname{}} 
\author{\authname}
\date{\today}

\maketitle

\pagenumbering{roman}

\section{Revision History}

\begin{tabularx}{\textwidth}{p{3cm}p{2cm}X}
\toprule {\bf Date} & {\bf Version} & {\bf Notes}\\
\midrule
2023/01/18 & 1.0 & Final Version\\
2023/04/05 & 2.0 & Revision 1\\
\bottomrule
\end{tabularx}

\newpage

\section{Reference Material}

This section records information for easy reference.

\subsection{Abbreviations and Acronyms}

\renewcommand{\arraystretch}{1.2}
\begin{tabular}{l l} 
  \toprule		
  \textbf{symbol} & \textbf{description}\\
  \midrule 
  AC & Anticipated Change\\
  M & Module \\
  MG & Module Guide \\
  MIS & Module Interface Specifications \\ 
  OS & Operating System \\
  FR & Functional Requirement\\
  SRS & Software Requirements Specification\\
  UC & Unlikely Change \\
  \wss{etc.} & \wss{...}\\
  \bottomrule
\end{tabular}\\

\newpage

\tableofcontents

\listoftables

\newpage

\pagenumbering{arabic}

\section{Introduction}

The following document explains the Module Guide for our Capstone project. Complementary documents include the System Requirement Specifications, (SRS), and the Module Interface Specifications, (MIS). 

The rest of the document is organized as follows. Section
\ref{SecChange} lists the anticipated and unlikely changes of the software
requirements. Section \ref{SecMH} summarizes the module decomposition that
was constructed according to the likely changes. Section \ref{SecMD} gives a detailed description of the modules. Section \ref{SecTM} includes two traceability matrices. One checks
the completeness of the design against the requirements provided in the SRS. The
other shows the relation between anticipated changes and the modules.

\section{Anticipated and Unlikely Changes} \label{SecChange}

This section lists possible changes to the system. According to the likeliness
of the change, the possible changes are classified into two
categories. Anticipated changes are listed in Section \ref{SecAchange}, and
unlikely changes are listed in Section \ref{SecUchange}.

\subsection{Anticipated Changes} \label{SecAchange}

Anticipated changes are the source of the information that is to be hidden
inside the modules. Ideally, changing one of the anticipated changes will only
require changing the one module that hides the associated decision. The approach
adapted here is called design for
change.

\begin{description}
\item[\refstepcounter{acnum} \actheacnum \label{acHardware}:] The color scheme of the GUI which means a change in the stylesheet.
\item[\refstepcounter{acnum} \actheacnum \label{acInput}:] The layout of the pages and buttons in the GUI which means a change in the ui files and animation modules.
\item[\refstepcounter{acnum} \actheacnum \label{acGuiInfo}:] Information that is displayed on each GUI page.
\item[\refstepcounter{acnum} \actheacnum \label{acDbStoring}:] The method of storing information in the database to accommodate for large amounts of data.
\item[\refstepcounter{acnum} \actheacnum \label{acAccountFields}:] The fields required for creating an account.
\item[\refstepcounter{acnum} \actheacnum \label{acDataStructures}:] The data structures for storing and manipulating data inside the software.
\item[\refstepcounter{acnum} \actheacnum \label{acBackendFrontend}:] The method of decomposing front and back-end functionality of GUI.
\end{description}

\subsection{Unlikely Changes} \label{SecUchange}

The module design should be as general as possible. However, a general system is
more complex. Sometimes this complexity is not necessary. Fixing some design
decisions at the system architecture stage can simplify the software design. If
these decision should later need to be changed, then many parts of the design
will potentially need to be modified. Hence, it is not intended that these
decisions will be changed.

\begin{description}
\item[\refstepcounter{ucnum} \uctheucnum \label{ucIO}:] Input device will be a keyboard and output device will be a screen. 
\item[\refstepcounter{ucnum} \uctheucnum \label{ucQt}:] The Qt library for creating the GUI
\item[\refstepcounter{ucnum} \uctheucnum \label{ucHardware}:] The hardware the GUI is running on
\item[\refstepcounter{ucnum} \uctheucnum \label{ucPython}:] The programming language (python) for the GUI
\item[\refstepcounter{ucnum} \uctheucnum \label{ucStoringUser}:] Storing test and user information in a database
\item[\refstepcounter{ucnum} \uctheucnum \label{ucAzure}:] Hosting the database on an Azure SQL Server
\item[\refstepcounter{ucnum} \uctheucnum \label{ucPowerBi}:] Visually displaying stored test information in Power BI
\end{description}

\section{Module Hierarchy} \label{SecMH}

This section provides an overview of the module design. Modules are summarized
in a hierarchy decomposed by secrets in Table \ref{TblMH}. The modules listed
below, which are leaves in the hierarchy tree, are the modules that will
actually be implemented.

\begin{description}
\item [\refstepcounter{mnum} \mthemnum \label{Arduino}:] mainArduino.ino
\item [\refstepcounter{mnum} \mthemnum \label{ESP8266}:] mainESP8266.ino
\item [\refstepcounter{mnum} \mthemnum \label{ui_main}:] ui\_main.py
\item [\refstepcounter{mnum} \mthemnum \label{ui_functions}:] ui\_functions.py
\item [\refstepcounter{mnum} \mthemnum \label{main}:] main.py
\item [\refstepcounter{mnum} \mthemnum \label{resource_rc}:] resource\_rc.py

\end{description}

\begin{table}[h!]
\centering
\begin{tabular}{p{0.3\textwidth} p{0.6\textwidth}}
\toprule
\textbf{Level 1} & \textbf{Level 2}\\
\midrule

\multirow{2}{0.3\textwidth}{Hardware-Hiding Module} & mainArduino.ino \\
& mainESP8266.ino \\
\midrule

\multirow{3}{0.3\textwidth}{Behaviour-Hiding Module} & ui\_main.py\\
& ui\_functions.py\\
& main.py\\
\midrule

{Software Decision Module} & {resource\_rc.py}\\
\bottomrule

\end{tabular}
\caption{Module Hierarchy}
\label{TblMH}
\end{table}

\section{Module Decomposition} \label{SecMD}

\subsection{Hardware Hiding Modules}

\subsubsection{mainArduino.ino (\mref{Arduino})}
\begin{description}
\item[Services:]Converts the input data taken from sensors into the data that is converted to data used by the UI. This function also provides the main program logic of the microcontroller of the board. It is used to initalize the microcontroller's pins, timers and other hardware components which all help in gathering data for our database.
\item[Implemented By:] [Arduino]
\end{description}

\subsubsection{mainESP8266.ino (\mref{ESP8266})}
\begin{description}
\item[Services:] An Arduino module establishes a Wi-Fi connection between the Arduino and PC to send data from the sensors and the Arduino to the PC. This allows us to collect and send data wirelessly through user application to our database wirelessly.
\item[Implemented By:] [Arduino, ESP8266]
\end{description}

\subsection{Behaviour-Hiding Module}

\subsubsection{ui\_main.py (\mref{ui_main})}

\begin{description}
\item[Services:] A PyQt designer generated module that sets up the application's window and design. This module has all functions and layout information for our user application. It also provides the code for the user interface components that make up the application.x`'
\item[Implemented By:] [PyQt]
\end{description}

\subsubsection{ui\_functions.py (\mref{ui_functions})}
\begin{description}
\item[Services:] A python module that imports all the necessary libraries for backend, contains class for UI functions and creates the connection to the database. This module also creates the functions that the user interacts while navigating through our user interface. It defines the function that the handle user inputs, such as button movements and mouse clicks
\end{description}

\subsubsection{main.py (\mref{main})}
\begin{description}
\item[Services:] A python module that imports backend functions and frontend setup of GUI. This is also used to start and run the desktop application and can be considered the interpreter that reads and executes the code.
\end{description}

\subsection{Software Decision Module}

\subsubsection{resource\_rc.py (\mref{resource_rc})}

\begin{description}

  \item[Services:] A python module generated by PyQt resource compiler and uses all the local resources to display images during runtime. It is used to embed binary resources, such as images, icons, or other data files, into PyQt.
  \item[Implemented By:] [PyQt] 
  \end{description}

\newpage
\section{Traceability Matrix} \label{SecTM}

This section shows two traceability matrices: between the modules and the
functional requirements from our SRS document and between the modules and the anticipated changes.

% the table should use mref, the requirements should be named, use something
% like fref
\begin{table}[H]
\centering
\begin{tabular}{p{0.2\textwidth} p{0.6\textwidth}}
\toprule
\textbf{Req.} & \textbf{Modules}\\
\midrule
FR1 & \mref{Arduino}\\
FR2 & \mref{Arduino}\\
FR3 & \mref{Arduino}, \mref{ESP8266}\\
FR4 & \mref{Arduino}, \mref{ESP8266}\\
FR5 & \mref{Arduino}\\
FR6 & \mref{ui_main}, \mref{ui_functions}\\
FR7 & \mref{ui_functions}, \mref{main}\\
FR8 & \mref{ui_functions}\\
FR12 & \mref{Arduino}, \mref{ESP8266}, \mref{ui_functions}\\
FR14 & \mref{Arduino}, \mref{ESP8266}, \mref{ui_main}, \mref{ui_functions}, \mref{main}\\
FR18 & \mref{ui_functions}, \mref{main}\\
\bottomrule
\end{tabular}
\caption{Trace Between Requirements and Modules}
\label{TblRT}
\end{table}

\begin{table}[H]
\centering
\begin{tabular}{p{0.2\textwidth} p{0.6\textwidth}}
\toprule
\textbf{AC} & \textbf{Modules}\\
\midrule
\acref{acHardware} & \mref{ui_main}\\
\acref{acInput} & \mref{ui_main}\\
\acref{acGuiInfo} & \mref{main}, \mref{ui_functions}\\
\acref{acDbStoring} & \mref{ui_functions}\\
\acref{acAccountFields} & \mref{ui_main}, \mref{ui_functions}\\
\acref{acDataStructures} & \mref{ui_functions}\\
\acref{acBackendFrontend} & \mref{ui_functions}, \mref{main}\\

\bottomrule
\end{tabular}
\caption{Trace Between Anticipated Changes and Modules}
\label{TblACT}
\end{table}

\newpage{}

\end{document}

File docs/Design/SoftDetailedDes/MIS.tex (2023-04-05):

\documentclass[12pt, titlepage]{article}

\usepackage{amsmath, mathtools}

\usepackage[round]{natbib}
\usepackage{amsfonts}
\usepackage{amssymb}
\usepackage{graphicx}
\usepackage{colortbl}
\usepackage{xr}
\usepackage{hyperref}
\usepackage{longtable}
\usepackage{xfrac}
\usepackage{tabularx}
\usepackage{float}
\usepackage{siunitx}
\usepackage{booktabs}
\usepackage{multirow}
\usepackage[section]{placeins}
\usepackage{caption}
\usepackage{fullpage}

\hypersetup{
bookmarks=true,     % show bookmarks bar?
colorlinks=true,       % false: boxed links; true: colored links
linkcolor=red,          % color of internal links (change box color with linkbordercolor)
citecolor=blue,      % color of links to bibliography
filecolor=magenta,  % color of file links
urlcolor=cyan          % color of external links
}

\usepackage{array}

\externaldocument{../../SRS/SRS}

\input{../../Comments}
\input{../../Common}

\begin{document}

\title{\huge Module Interface Specification \\\progname{}}

\author{\authname}

\date{\today}

\maketitle

\pagenumbering{roman}

\section{Revision History}

\begin{tabularx}{\textwidth}{p{3cm}p{2cm}X}
\toprule {\bf Date} & {\bf Version} & {\bf Notes}\\
\midrule
2023/01/18 & 1.0 & Final Version\\
2023/04/05 & 2.0 & Revision 1\\
\bottomrule
\end{tabularx}

~\newpage

\section{Symbols, Abbreviations and Acronyms}

See SRS Documentation at \url{https://github.com/ahmed-nazir/Capstone/blob/main/docs/SRS/SRS.pdf} \wss{give url}

\wss{Also add any additional symbols, abbreviations or acronyms}

\newpage

\tableofcontents

\newpage

\pagenumbering{arabic}

\section{Introduction}

The following document details the Module Interface Specifications for the Formulate system. Formulate enables teams to streamline data collection and storage, resulting in testing overhead reduction and increased control of raw test data gathered by automating aspects of the testing procedure. \\
\wss{Fill in your project name and description}

Complementary documents include the System Requirement Specifications
and Module Guide.  The full documentation and implementation can be
found at \url{https://github.com/ahmed-nazir/Capstone}.  \wss{provide the url for your repo}

~\newpage

\section{MIS \wss{Module Name}} \label{Module} \wss{Use labels for
  cross-referencing}
This section describes all the modules and their respective classes and/or functions. It should be noted that exception handling only applies to some
modules as some of them are automatically generated by external software and do not require error handling.
\wss{You can reference SRS labels, such as R\ref{R_Inputs}.}

\wss{It is also possible to use \LaTeX for hypperlinks to external documents.}

  \subsection{Module - ui\_main.py}

  \subsubsection{Description}
  Python file generated by PyQt designer which sets up the application’s window and its design

  \subsubsection{Classes}
  \textbf{Class:} Ui\_MainWindow() - Contains all methods for setting up the application’s window and its static front end design \\

    \noindent \begin{tabular}{| p{0.6\textwidth} | p{0.2\textwidth}| p{0.2\textwidth}|}
      \hline
      \rowcolor[gray]{0.9}
      Methods & Parameters & Return\\
      \hline
      setupUi() - Takes a PyQt MainWindow object and sets up it’s layout according to the ui file created in designer &Self, MainWindow [QMainWindow] & None \\
      \hline
      retranslateUi() - Sets the static text of the GUI’s buttons and labels & Self, MainWindow [QMainWindow] & None \\
      \hline
    \end{tabular}

    %AHMED - ADDED MY NEW FUNCTIONS

    %MOH PLEASE ADD YOUR NEW FUNCTIONS HERE
    \newpage
    \subsection{Module - ui\_functions.py}

    \subsubsection{Description}
    Imports all necessary libraries for backend functions, creates connection to database, and contains class for UI functions
    
    \subsubsection{Classes}
    \textbf{Class:} UIFunctions() - Contains the functions that are connected to buttons in the application’s UI \\
    
      \noindent \begin{tabular}{| p{0.6\textwidth} | p{0.2\textwidth}| p{0.2\textwidth}|}
        \hline
        \rowcolor[gray]{0.9}
        Methods & Parameters & Return\\
        \hline
        toggleMenu() - Handles the animation for toggling the side menu &Self, maxWidth [integer], enable [boolean] & None \\
        \hline
        login\_into\_app() - Checks if the enter username/password are valid and correct and signs user into their account & Self & None \\
        \hline
        continue\_signup() - Checks if all the sign up fields are valid and stores account/login details in database & Self & None \\
        \hline
        move\_to\_submit\_test() - Ensures that only logged in users are allow to reach the submit test page & Self & None \\
        \hline
        browse\_and\_display\_pictures() - Opens a popup where users are allowed to navigate through their file directory, select a picture, and display that picture in the UI & Self & None\\
        \hline
        upload\_test\_info() - Submits test data and user-inputed test information to the database, and uploads test picture to azure blob storage & Self & None \\
        \hline
        startTest() - Starts the test on the device and begins collecting data & Self & None\\
        \hline
        runProg() - Creates another thread which will allow the GUI to be operable while it is conducting tests & Self & None\\
        \hline
        stopTest() - Stops reading values from the Arduino and gathers all the data in a viewable table & Self & None\\
        \hline
        declineData() - Erases the data collected from the last test and does not submit it to the database & Self & None\\
        \hline
        submitData() - Submits data from the test to the Azure database & Self & None\\
        \hline
        retrieveData() - Retrieves data from the local onboard storage & Self & None\\
        \hline
        connect\_wireless() - Connects to the device via Wi-Fi & Self & None\\
        \hline
        disconnect\_wireless() - Disconnects the PC from the device Wi-Fi network & Self & None\\
        \hline
        connectWired() - Connects to the device via COM port (wired connection) & Self & None\\
        \hline
        disconnect\_wired() - Disconnects from the COM port currently connect & Self & None\\
        \hline
        view\_dashboard() - Directs user to PowerBi dashboard on their browser & Self & None\\
        \hline
        ping() - Retrieves the currently configured sensors and displays it for the user & Self & None\\
        \hline
        select\_com() - Checks the current COM ports detected and displays them in a drop down & Self & None\\
        \hline
      \end{tabular}

      \noindent \begin{tabular}{| p{0.6\textwidth} | p{0.2\textwidth}| p{0.2\textwidth}|}
        \hline
        \rowcolor[gray]{0.9}
        Methods & Parameters & Return\\
        \hline
        make\_config\_page() - Loads the saved sensors in the configuration page drop down & Self & None\\
        \hline
        autofill\_config() - Automatically fills out the fields in the sensor config menu when users select a saved sensor & Self & None\\
        \hline
        gen\_config\_sensors() - Generates the Arduino code if the fields are not empty & Self & None\\
        \hline
        saveConfiguration1() - Saves the sensor configuration for sensor 1 in savedSensors.json & Self & None\\
        \hline
        saveConfiguration2() - Saves the sensor configuration for sensor 2 in savedSensors.json & Self & None\\
        \hline
        saveConfiguration3() - Saves the sensor configuration for sensor 3 in savedSensors.json & Self & None\\
        \hline
        saveConfiguration4() - Saves the sensor configuration for sensor 4 in savedSensors.json & Self & None\\
        \hline
      \end{tabular}

  \subsubsection{Functions}
    \noindent \begin{tabular}{| p{0.6\textwidth} | p{0.2\textwidth}| p{0.2\textwidth}|}
      \hline
      \rowcolor[gray]{0.9}
      Function & Parameters & Return\\
      \hline
      hash\_new\_password() - Generates a hashed password based on the user’s inputted password & password [string] & salt [string], hashed\_pass [string] \\
      \hline
      is\_correct\_password() - Checks if inputted password matches stored password in database & salt\_hex [string], stored\_hash [string], pass\_to\_check [string] & Boolean \\
      \hline
      connect\_to\_database() - Creates a connection to the database to be able to read and write values from the application to the database & None & conn [connection object], cursor [cursor object] \\
      \hline
    \end{tabular}

\newpage

  \subsubsection{Exception Handling}
  Input validation of the user information and try/except statements are the main forms of exception handling. 
  User fields for signing up are checked to ensure that they are not empty and that the password follows the 
  rules of having 8 minimum characters and includes an alphabet, number, and an non-alphanumeric character. 
  When logging in, inputted passwords are checked to ensure that they match the passwords stored in the database.
  In addition, most functions preform their work in a try statement and deal with errors in a except statement.
  Connectivity to the device and logged in state of users are checked before they are able to move to 'Start Test' and 'Submit Test' pages, respectively.
  Furthermore, checks for empty user fields or test information are checked before test data is submitted. If any of these conditions fail, an exception
  is raised which gets handled in the except statements. The except statements create an error popup with the appropriate message to signal to the user
  where they have gone wrong.  

  \subsection{Module - arduino\_code\_generator.py}
  \subsubsection{Description}
  This module generates Arduino code based on the users inputs in the configure sensors page. It produces a mainArduino.ino file which the user can use to flash their Arduino.
  \subsubsection{Classes}
    \textbf{Class:} CodeGenerator() - Contains the functions that write the Arduino code \\
    
      \noindent \begin{tabular}{| p{0.6\textwidth} | p{0.2\textwidth}| p{0.2\textwidth}|}
        \hline
        \rowcolor[gray]{0.9}
        Methods & Parameters & Return\\
        \hline
        generate() - gets the data which give information on the sensors attached and generates the mainArduino.ino file  & data & None \\
        \hline
      \end{tabular}

\newpage
  \subsection{Module - main.py}

  \subsubsection{Description}
  Imports backend functions and frontend setup of GUI. This is also used to start and run the desktop application

  \subsubsection{Classes}
  \textbf{Class:} MainWindow() - Initializes a PyQt main window that is defined in ui\_main.py and connects the buttons in the desktop application’s UI to backend functions defined in ui\_functions.py \\

    \noindent \begin{tabular}{| p{0.6\textwidth} | p{0.2\textwidth}| p{0.2\textwidth}|}
      \hline
      \rowcolor[gray]{0.9}
      Methods & Parameters & Return\\
      \hline
      \_\_init\_\_() - Initializes the application and connects UI buttons to backend functions &  Self & None \\
      \hline
      changeText() - Add text to menu buttons when toggling full side menu and vice-versa & Self & None \\
      \hline
    \end{tabular}

  \subsection{Module - resource\_rc.py}

  \subsubsection{Description}
  Python file generated by PyQt resource compiler and sets up all the PyQt resources (local images) to be displayed during runtime of application

  \subsubsection{Functions}
  
    \noindent \begin{tabular}{| p{0.6\textwidth} | p{0.2\textwidth}| p{0.2\textwidth}|}
      \hline
      \rowcolor[gray]{0.9}
      Function & Parameters & Return\\
      \hline
      qInitResources() - Registers the raw byte data of each image to the Qt resource system &  None & None \\
      \hline
      qCleanupResources() - Unregisters the raw byte data of each image to the Qt resource system & None & None \\
      \hline
    \end{tabular}

\newpage
    \subsection{Module - mainArduino.ino}

    \subsubsection{Description}
    This module runs on the Arduino and collects all the data from the various sensors connected to it. It also takes the data and sends it to the PC wired or wirelessly.

  \subsubsection{Functions}
    \noindent \begin{tabular}{| p{0.6\textwidth} | p{0.2\textwidth}| p{0.2\textwidth}|}
      \hline
      \rowcolor[gray]{0.9}
      Function & Parameters & Return\\
      \hline
      setup() - Initializes all the sensors, SD card module and the serial communication lines between the PC and Wi-Fi module & None & None \\
      \hline
      loop() - This function reads data from the sensors and creates a bytestring to send to the PC & None & None \\
      \hline
      
    \end{tabular}

    \subsection{Module - mainESP8266.ino}

    \subsubsection{Description}
    This module runs on the NodeMCU (ESP8266) and allows for the Arduino to send data to it and relay that information to the PC via Wi-Fi.

  \subsubsection{Functions}
    \noindent \begin{tabular}{| p{0.6\textwidth} | p{0.2\textwidth}| p{0.2\textwidth}|}
      \hline
      \rowcolor[gray]{0.9}
      Function & Parameters & Return\\
      \hline
      setup() - Initializes the ESP8266 as a wireless access point so our PC can connect to it, it also initializes the serial port to allow for communication between the PC and Arduino & None & None \\
      \hline
      loop() - This function acts as a relay to pass information sent from the Arduino to the PC via TCP and also send information from the PC to the Arduino & None & None \\
      \hline
      
    \end{tabular}

\newpage

\newpage

%\section{Appendix} \label{Appendix}
%N/A \\
\wss{Extra information if required}

\end{document}

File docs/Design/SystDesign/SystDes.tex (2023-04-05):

\documentclass[12pt, titlepage]{article}

\usepackage{fullpage}
\usepackage[round]{natbib}
\usepackage{multirow}
\usepackage{booktabs}
\usepackage{tabularx}
\usepackage{graphicx}
\usepackage{float}
\usepackage{hyperref}
\usepackage{colortbl}
\usepackage[table]{xcolor} 
\hypersetup{
    colorlinks,
    citecolor=blue,
    filecolor=black,
    linkcolor=red,
    urlcolor=blue
}

\input{../../Comments}
\input{../../Common}

\newcounter{acnum}
\newcommand{\actheacnum}{AC\theacnum}
\newcommand{\acref}[1]{AC\ref{#1}}

\newcounter{ucnum}
\newcommand{\uctheucnum}{UC\theucnum}
\newcommand{\uref}[1]{UC\ref{#1}}

\newcounter{mnum}
\newcommand{\mthemnum}{M\themnum}
\newcommand{\mref}[1]{M\ref{#1}}

\begin{document}

\title{\huge{System Design} \\ \progname{}} 
\author{\authname}
\date{\today}

\maketitle

\pagenumbering{roman}

\section{Revision History}

\begin{tabularx}{\textwidth}{p{3cm}p{2cm}X}
\toprule {\bf Date} & {\bf Version} & {\bf Notes}\\
\midrule
2023/01/14 & 1.0 & General Updates\\
2023/01/18 & 2.0 & Final Version\\
2023/04/05 & 3.0 & Revision 1\\
\bottomrule
\end{tabularx}

\newpage

\section{Reference Material}

This section records information for easy reference.

\subsection{Abbreviations and Acronyms}

\renewcommand{\arraystretch}{1.2}
\begin{tabular}{l l} 
  \toprule		
  \textbf{symbol} & \textbf{description}\\
  \midrule 
  \progname & Mechatronics Engineering Capstone Course\\
  UART & Universal Asynchronous Receiver-Transmitter\\
  SPI & Serial Peripheral Interface\\
  I2C & Inter-Integrated Circuit\\
  USB & Universal Serial Bus\\
  TCP & Transmission Control Protocol\\
  IP & Internet Protocol\\
  SPDT & Single pole, double throw \\
  TCP/IP & Transmission Control Protocol / Internet Protocol \\
  SOC & Software On Chip \\
  SPST & Single pole, single throw \\
  TX & Transmit \\
  RX & Recieve \\
  USB & Universal Serial Bus \\
  LED & Light-emitting diode \\
  GB & GigaByte \\
  SD & Secure Digital \\
  PCB & Printed Circuit Board \\
  \bottomrule
\end{tabular}\\

\newpage

\tableofcontents

\newpage

\listoftables

\listoffigures

\newpage

\pagenumbering{arabic}

\section{Introduction}

The system design document establishes the group's development considerations for the Formulate system. The motivations which drove each aspect of the design were referenced back to the System Requirements Specification, Hazard Analysis, and Development Plan documents. 

\wss{Include references to your other documentation}

\section{Purpose}

\wss{Purpose of your design documentation}

\wss{Point to your other design documents}

Documentation of the Formulate system's design serves to improve the maintainability, reusability, and understandability of the project. This is accomplished through the system design, software architecture, and software detailed design documents by detailing how the design addressed the requirements outlined in the documents from this document's introduction. \\

\section{Scope}

\wss{Include a figure that show the System Context (showing the boundary between
your system and the environment around it.)}

This document in particular focuses on the considerations for the user interface, mechanical, electrical, and communication protocol aspects of the system. All relevant design decisions relating to the requirements were detailed by each aspect of the system, and any visual components used to aid the design were included at the end of the document by each aspect of the system. \\ 

\newpage

\subsection{System Context Diagram}
\begin{figure}[h!]
  \begin{center}
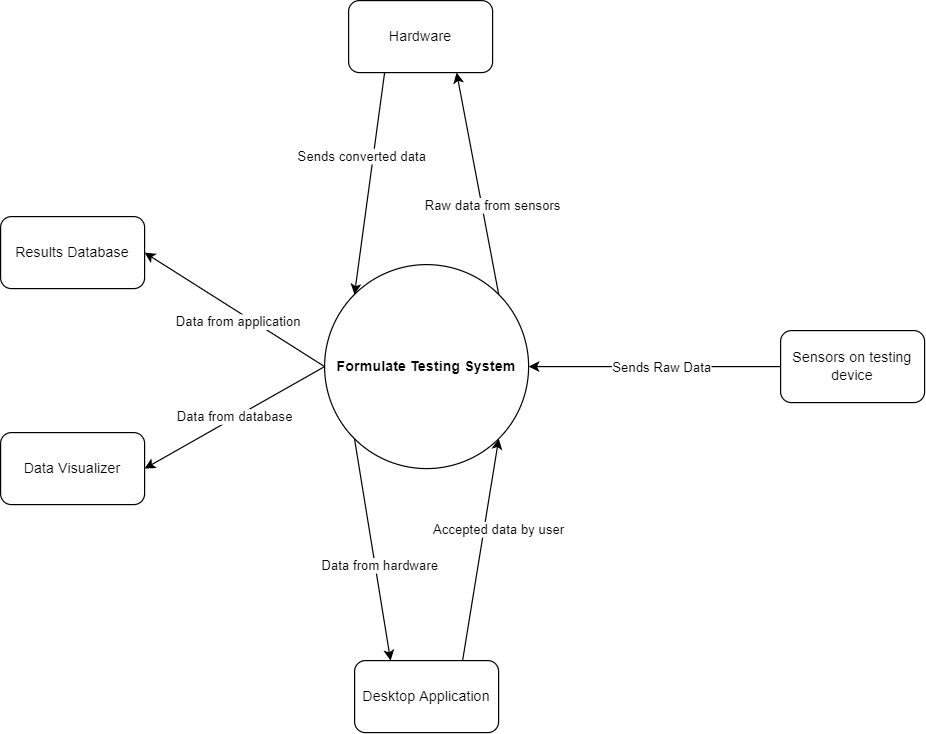
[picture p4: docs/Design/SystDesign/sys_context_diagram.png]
  
  \caption{Formulate Context Diagram}
  \end{center}
  \end{figure}
  \newpage

\section{Project Overview}

\subsection{Normal Behaviour}
During normal operation the device should work as follows, the user has an option to either connect wired or wirelessly to our device, regardless of which method they choose the results will be consistent between the two. To connect to the device the user will open our desktop application and either create an account or log in to an existing account. This will lead them to the home page where the user will select the connection method as wireless or wired.\\

%Stephen updated this section, Sunday afternoon
Before the user can start any testing they will need to secure our device on the vehicle they are testing with. Our device mounts to the car via a DIN rail. The DIN rail is secured to a relatively flat plane of the car via M6 bolts, and the device has a snap on mechanism onto the DIN rail. After the device is secure the user will need to ensure that all the correct sensors are attached. To conduct any testing the user will first fill out the test parameters of the specific test they are conducting via a sensor configuration page. The user will then go to the test page in our application and start the test. During the test, our hardware will collect the sensor data and send it to the application. When the user stops the test they will be able to preview all the raw data collected from the test and can either decline the data or send it to the database. Before the user sends data to the database, they can add descriptive text to contextualize the test data and provide a picture of the test data. Whent the sensor test data is sent to the database, all the sensor data along with the test description and picture will be sent.\\

The user can view previous test data using the Power Bi dashboard to read all data in the database with visualized statistics from collected data. The Power Bi dashboard will allow the user to do comparisons between tests and quickly analyze if the tests conducted met the users expectations.

\begin{figure}[h!]
  \begin{center}
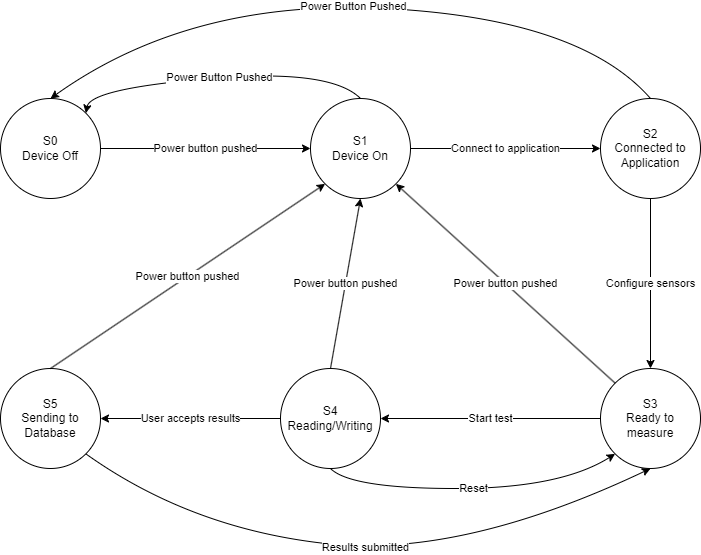
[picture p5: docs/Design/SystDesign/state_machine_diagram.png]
  
  \caption{Finite State Machine}
  \end{center}
  \end{figure}
  \newpage

\subsection{Undesired Event Handling}
There might be cases where undesired events occur and to minimize any issues caused to the user we tried to account for them
\subsubsection{Loss of Connection}
%Stephen updated this section, Sunday afternoon
If at any point the connection between the PC and the device fails, such as when the device moves out of wireless connectivity range, a fail-safe test data storage system is required to ensure that no testing data is lost. Whenever data is sent to the application, the data is also simultaneously sent to the local storage on the device. The onboard MicroSD Card will save the entire contents of a previous test that the user can recover in the event of failure.

\subsubsection{Excessive Vibration/Shaking}
%Stephen updated this section, Sunday afternoon
Since our device is expected to be used in an environment with large vibrations, we decided to create a custom PCB instead of using normal jumper cables and a breadboard. This ensures that the electrical connections between the micro-controller, local memory module, and wi-fi module can maintain reliable electrical connections during tests.

\subsubsection{Loss of Data Packets}
When data from our device is sent to the PC, a situation where data is lost or an entire string of data was incorrectly sent can occur. To ensure we are only reading data from complete bytestrings, each bytestring will start with 'B' and ends with 'E' and our python program checks to make sure that the data we are saving has both those values.

\wss{How you will approach undesired events}

\newpage
\subsection{Component Diagram}
\begin{figure}[hbt!]
  \begin{center}
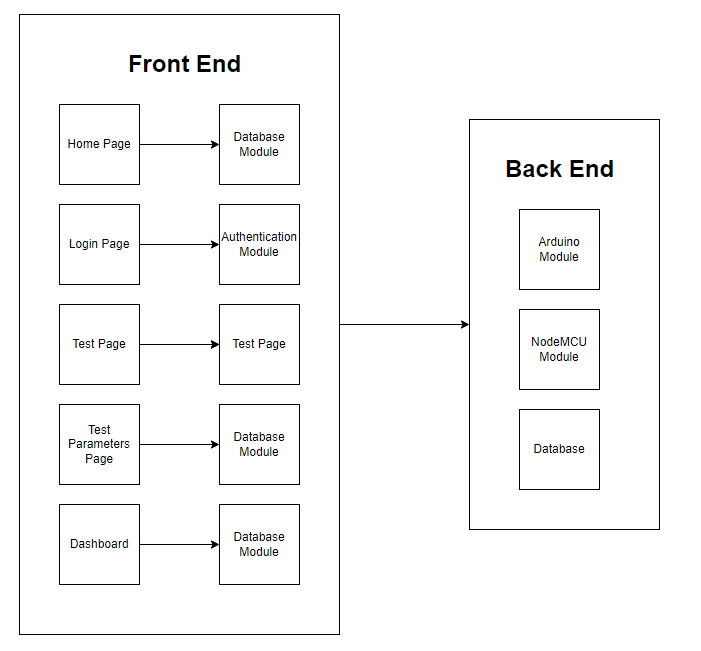
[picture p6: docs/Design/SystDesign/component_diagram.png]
  
  \caption{Component Diagram} 
  \end{center}
  \end{figure}

\newpage
\subsection{Connection Between Requirements and Design} \label{SecConnection}
The following requirements are from the SRS document.

\begin{itemize}
  \item[FR1,FR5:] To measure vibration we chose to use an accelerometer that outputs in units of G's. For temperature, we are using an LM35 temperature sensor which provides temperature in celsius and has an accuracy of +- 1 degree. To measure humidity we are using a DHT11 sensor which gives us the relative humidity in percent. The accelerometer also provides shock data which just needs some post-processing
  \item[FR2:] The device transmits data using the UART protocol to the PC when it is connected via a wire.
  \item[FR3,FR4:] The device will have the start and stop buttons to control the tests inside the desktop application so the user can conduct tests remotely.
  \item[FR6:] The user can preview the data after a test once they stop the test. A table will populate with all the raw data from the test on the testing page of the desktop application
  \item[FR7:] After the user previews the test they will be able to decline or submit the test to our database. The table of test values will be sent to our Azure database once the user approves.
  \item[FR8:] The Power Bi dashboard will connect to the Azure database and will be able to read all the test data
  \item[FR9:] The device will be clamped down to a DIN Rail
  \item[FR11:] Our device is going to contain one 9V batteries to power the entire device. 9V batteries allows for the user to quickly swap old batteries for new ones when they lose charge.
  %Stephen updated this section, Sunday afternoon
  \item[FR12,FR15:] The ESP8266 wi-fi module allows our device to wirelessly communicate with our desktop application through Wi-Fi. TCP will be used to send data back and forth.
  \item[FR14:] The screw down style terminal blocks provides a rigid electrical connection between the sensor conductors and the device.
  \item[FR16:]  The device has an onboard programming mode switch allowing users to change the setting on the ESP8266 wi-fi module or the Arduino 
  \item[FR17:] The device will have a screw down style terminal block which will allow users to connect to 5 digital ports and 5 analog ports      
  
\end{itemize}

\wss{The intention of this section is to document decisions that are made
  ``between'' the requirements and the design.  To satisfy some requirements,
  design decisions need to be made.  Rather than make these decisions implicit,
  they are explicitly recorded here.  For instance, if a program has security
  requirements, a specific design decision may be made to satisfy those
  requirements with a password.}

\newpage
\section{System Variables}

\wss{Include this section for Mechatronics projects}

\subsection{Monitored Variables}
  \begin{table}[!h]
  \begin{tabular}{| p{0.23\textwidth} | p{0.10\textwidth}| p{0.10\textwidth}| p{0.46\textwidth}|}
    \hline
    \rowcolor[gray]{0.9}
    Monitored Variable & Type & Units & Description\\
    \hline
    m\_vibration & Analog& V& A signal monitoring the vibration resistance of the motor \\
    \hline
    m\_humidity & Analog & V & A signal monitoring the humidity of the motor’s environment \\
    \hline
    m\_temperature & Analog & V & A signal monitoring the temperature of the motor’s environment \\
    \hline
    m\_shock & Analog & V & A signal monitoring the shock resistance of the motor \\
    \hline
    m\_conv\_vibration & Digital & g  & Converted vibration values that are in useful units \\
    \hline
    m\_conv\_humidity & Digital & \% & Converted humidity values that are in useful units \\
    \hline
    m\_conv\_temperature & Digital & \textdegree C & Converted temperature values that are in useful units \\
    \hline
    m\_conv\_shock & Digital & g & Converted shock values that are in useful units \\
    \hline
    m\_data\_accepted & Digital & T/F & Determines if user has accepted the results and wants to send it to the database \\
    \hline
  \end{tabular}
  \caption{Monitored Variables}
  \end{table}

\subsection{Controlled Variables}
  \begin{table}[!h]
  \begin{tabular}{| p{0.23\textwidth} | p{0.10\textwidth}| p{0.10\textwidth}| p{0.46\textwidth}|}
    \hline
    \rowcolor[gray]{0.9}
    Controlled Variable & Type & Units & Description\\
    \hline
    c\_green\_light& Digital& 1/0& Green LED light on testing device that indicates passed measurements \\
    \hline
    c\_red\_light& Digital & 1/0 & Red LED light on testing device that indicates failed measurements \\
    \hline
    c\_sent\_to\_database & Digital & T/F & Determines if results displayed on the application are sent to the database \\
    \hline
  \end{tabular}
  \caption{Controlled Variables}
  \end{table}

\subsection{Constants Variables}
  \begin{table}[!h]
  \begin{tabular}{| p{0.23\textwidth} | p{0.10\textwidth}| p{0.10\textwidth}| p{0.46\textwidth}|}
    \hline
    \rowcolor[gray]{0.9}
    Constant & Units & Value & Description\\
    \hline
    k\_temperature\_range& \textdegree C& 5-40& Acceptable ambient temperature values for a Formula Electric motor \\
    \hline
    k\_humidity\_range& \% & 5-85 & Acceptable relative humidity values for a Formula electric motor \\
    \hline
    k\_max\_shock & g & 100 & Maximum shock resistance for a Formula Electric motor \\
    \hline
    k\_max\_vibration & g & 20 & Maximum vibration resistance for a Formula Electric motor \\
    \hline
  \end{tabular}
  \caption{Constants Variables}
  \end{table}

\section{User Interfaces}

\subsection{Desktop Application}
The user interface for the desktop application is designed through Qt designer, a software for designing and building GUIs through the Qt library. Qt designer generates UI files which can be converted to python scripts that build the static design and layout of the GUI. The desktop application is essentially multiple pages stacked on each other that change based on which buttons are clicked. The GUI is comprised of a left bar menu, top bar, and content pages being in the center, refer to figure 1 and 2 in the Appendix. Navigation through the application is done using the sidebar menu, where users can toggle the full menu and press on which page they want to go. The top bar will be used for extra functionality such as accessing user details, minimizing screen, etc. Users interact with the application using buttons to perform a variety of functions and form fields in which they can enter test/user information.

\subsection{Hardware}
The user will interface with the hardware as follows, they will mount a sensor to the top of our device and connect the sensor conductors to the device via a terminal block which is on either side of the device. The device will then be mounted to the Formula vehicle and the rest of the operations will take place on the Desktop Application.
\newpage
\subsection{Web Dashboard}
The user interface for the dashboard will allow the user to visualize data received from the database through a dashboard using Power Bi. After a test is conducted the user will be able to view the data on the Power Bi website. It will prompt the user to view the data in a variety of graphs and tables which will allow the user to interpret the data in more manageable and understandable way. The design is made with user in mind allowing them to find and view the data in the dashboard in a variety of ways since different types of data will be stored in the database.

\wss{Design of user interface for software and hardware.  Attach an appendix if
needed. Drawings, Sketches, Figma}

\section{Design of Hardware}

The hardware for our project will include a 3D-printed chassis that will house all electrical components. Our chassis was designed to meet the requirements outlined in our SRS document. The ability to easily mount the device on the Formula Electric vehicle was an important feature of the chassis. We are implementing a DIN rail connection solution to mount the device to any flat, planar surface on the car.

\wss{Most relevant for mechatronics projects}
\wss{Show what will be acquired}
\wss{Show what will be built, with detail on fabrication and materials}
\wss{Include appendices as appropriate, possibly with sketches, drawings, CAD, etc}

\newpage
\section{Design of Electrical Components}

\wss{Most relevant for mechatronics projects}
\wss{Show what will be acquired}
\wss{Show what will be built, with detail on fabrication and materials}
\wss{Include appendices as appropriate, possibly with sketches, drawings,
circuit diagrams, etc}

The electrical components were selected to address the functional requirements regarding robust sensor connection points, wireless functionality, and backup data collection capabilities. These capabilities were enabled using hardware modules selected to interface with the embedded device. \\

The Arduino Uno R3 (Uno) was the choice electrical component for the device's microcontroller. While other microcontrollers on the market were also capable of flexibly collecting data from a multitude of sensors, the Uno stood out as the optimal choice because of low monetary cost in hardware and the relatively high accessibility at large e-commerce platforms for the Formula Electric Team to purchase. In addition, the likelihood of the Formula Electric team using parts of the testing budget on the microcontroller was minimized as many Formula Electric members already posessed an Uno board. \\
%Stephen updated this section, Sunday afternoon
To support testing application flexibility in cases where no direct connections to power were available, one 9 volt batterywith a battery holder was used to provide the Uno with adequate power for on vehicle testing sessions. \\

A single pole, single throw (SPDT) power switch was used to quickly connect and disconnect the single 9 volt battery with the circuit connecting all electrical components. The switch was oriented such that the common pin actuated to connect either the 9V battery to the circuit or the circuit directly to ground. \\

Although the Uno provided many functionalities, the standard Uno model did not natively support wireless communication capabilities. As a result, the group chose to integrate a hardware module capable of a Transmission Control Protocol / Internet Protocol (TCP/IP) stack through an ESP8266 Software On Chip (SOC). The electrical component containing the ESP8266 SOC that was selected was the Node MCU 1.0. The Node MCU 1.0 is a development board with the ESP8266 SOC already built onto the Node MCU's PCB in addition to an on-board voltage regulator for the development board's 3.3 volt input power requirement. \\

A single pole, single throw (SPST) switch packaged with four ports was also required to interface the Node MCU 1.0 module with the Uno during initial device comissioning. Specifically, three of the four ports were used to disconnect the 3.3 volt power, transmit (TX), and recieve (RX) signal between the wifi module and the microcontroller when flashing the wifi module with firmware via a micro Universal Serial Bus (USB) port. When the one time firmware flash is complete, the three switches could be actuated to reconnect the power and signal connections between the two components. Despite the connect/disconnect functionality requiring only three of the four ports, a four port SPST switch was selected due to the high accesibility on large electronics e-commerce platforms relative to three port SPST switches. \\

Two diagnostic light-emitting diode's (LED) were used to provide the user with feedback on the live transmission status of the wifi module. The first diagnostic signal conveyed when the microcontroller was powered on. The second diagnostic signal conveyed when the wifi module was connected via Wi-Fi to the desktop application.  \\

Backup data storage to local memory in the event of wireless communication error due to the wifi module's failure or device operation outside the wifi router's range necessitated the use of a local memory storage electrical component. A 32 GigaByte (GB) micro Secure Digital (SD) card paired with a micro SD card adapter was used to provide the Uno with local memory storage to concurrently write test data to the SD card while also sending data over wifi to the desktop application. SanDisk, the microSD card manufacturer, was chosen primarily due to their cost effectiveness against other microSD manufacturers as measured by GB/dollar. Similarly, Geek Story was used as the microSD card adapter manufacturer as a result of their cost-effectiveness. \\

Robust sensor connection components between the sensor and the Uno's input ports were required for tests in physically demanding scenario's as loose or broken connections from high vibration or shock compromised the reliability of the sensor readings and thus the test data. As a result, Phoenix Contact's through hole, 10 port terminal blocks were used because the terminal block style connections provided a stronger connective interface between the sensor conductors and the Uno's ports. \\

Robust connections between all components of the circuit such as the electrical connections between the Uno, wifi module, micro SD card adapter, switches, and LED's also required a more robust solution relative to jumper wires. As a result, the group chose to design and manufacture a Printed Circuit Board (PCB) onto which all electrical components outlined could be soldered onto the board for a higher strength connection. \\
\newpage

The required electrical connections between the micro SD adapters pinouts and the Uno's pinouts were first outlined to organize the connection layout in the table below. \\

\begin{table}[H]
  \centering
  \begin{tabular}{|p{2cm}|p{6cm}|p{2cm}|p{2cm}|}
  \hline
  \rowcolor[gray]{0.9}
  \multicolumn{1}{|c|}{\textbf{Pin Name}} & \multicolumn{1}{c|}{\textbf{Pin Description}} & \multicolumn{1}{|c|}{\textbf{Arduino Port}} & \multicolumn{1}{|c|}{\textbf{Arduino Port Description}} 
  \\ \hline
  VCC
  & 5 Volt
  & 5 Volt
  & Power output
  \newline                                
  \\ \hline

  GND                              
  & Ground
  & Ground
  & Ground
  \newline                                
  \\ \hline

  MISO                          
  & SPI output from microSD
  & 12
  & Digital I/O
  \newline                                
  \\ \hline

  MOSI                                
  & SPI input to microSD
  & 11 
  & Digital I/O
  \newline                            
  \\ \hline

  SCK                                
  & Synchronize data transmission via Arduino clock
  & 13 
  & Digital I/O
  \newline                            
  \\ \hline

  CS                                
  & Select slave device on SPI bus
  & 10 
  & Digital I/O
  \newline                            
  \\ \hline

  \end{tabular}
  \caption{MicroSD Adapter to Uno Pinout}
\end{table}

The required electrical connections between the wifi module's pinouts and the Uno's pinouts were also outlined to organize the connection layout in the table below. \\

\begin{table}[H]
  \centering
  \begin{tabular}{|p{2cm}|p{6cm}|p{2cm}|p{2cm}|}
  \hline
  \rowcolor[gray]{0.9}
  \multicolumn{1}{|c|}{\textbf{Pin Name}} & \multicolumn{1}{c|}{\textbf{Pin Description}} & \multicolumn{1}{|c|}{\textbf{Arduino Port}} & \multicolumn{1}{|c|}{\textbf{Arduino Port Description}} 
  \\ \hline
  3V3
  & 3.3 Volt
  & 3.3 Volt
  & Power output
  \newline                                
  \\ \hline

  GND                              
  & Ground
  & Ground
  & Ground
  \newline                                
  \\ \hline

  TX                          
  & Transmit
  & 2
  & Digital I/O
  \newline                                
  \\ \hline

  RX                                
  & Recieve
  & 3
  & Digital I/O
  \newline                            
  \\ \hline

  \end{tabular}
  \caption{Wi-Fi Module to Uno Pinout}
\end{table}

\newpage

A final list of the required electrical components was shown below. \\

\begin{table}[H]
  \centering
  \begin{tabular}{|p{3cm}|p{2cm}|p{4cm}|p{4cm}|p{2cm}|}
  \hline
  \rowcolor[gray]{0.9}
  \multicolumn{1}{|c|}{\textbf{Component}} & \multicolumn{1}{c|}{\textbf{Manufacturer}} & \multicolumn{1}{c|}{\textbf{Part Number}} & \multicolumn{1}{c|}{\textbf{Description}} & \multicolumn{1}{|c|}{\textbf{Quantity}}
  \\ \hline
  %Stephen updated this section, Sunday afternoon
  Microcontroller
  & Arduino
  & Uno R3
  & System micro-controller
  & 1
  \newline                                
  \\ \hline

  Wifi Module                              
  & NodeMCU
  & 1.0
  & System wifi 
  & 1
  \newline                                
  \\ \hline

  Micro SD Adapter                          
  & Geek Story
  & N/A
  & Local memory interface
  & 1
  \newline                                
  \\ \hline

  Micro SD Card                                
  & Sandisk
  & SDSQUAR-032G-GN6MA
  & System local memory
  & 1
  \newline                            
  \\ \hline

  Battery                                
  & Duracell
  & 4330206640
  & System power
  & 1
  \newline                            
  \\ \hline

  SPST Switch                                
  & E-Switch
  & 100SPTITI1B4M2QE
  & System power switch
  & 1
  \newline                            
  \\ \hline

  4 Port SPST Switch                                
  & TE
  & 435640-2
  & Wifi signal control switch
  & 1
  \newline                            
  \\ \hline

  Through Hole Terminal Block                                
  & Phoenix Contact
  & 1715789
  & System sensor ports
  & 2
  \newline                            
  \\ \hline

  LED                                
  & Kingbright
  & WP7113ID5V
  & LED Resistor
  & 2
  \newline                            
  \\ \hline

  Custom PCB                                
  & JLCPCB
  & N/A
  & System PCB
  & 1
  \newline                            
  \\ \hline

  \end{tabular}
  \caption{Component List}
\end{table}

The electrical schematic for the overall circuit containing all components was designed in Kicad and was shown in Appendix C. The PCB layout was also designed in Kicad and was shown in Appendix C. The PCB layout was then fabricated by the manufacturer JLCPCB. \\

\newpage

\newpage
\section{Design of Communication Protocols}
Our project mainly uses two ways to communicate. The user will either directly plug the device into their computer or they will wirelessly communicate with the device over Wi-Fi. Each of the sensors that are connected to the Arduino uses different protocols to send data.

\begin{table}[!h]
\begin{tabular}{| p{0.50\textwidth} | p{0.30\textwidth}|}
  \hline
  \rowcolor[gray]{0.9}
  Device & Communication Protocol \\
  \hline
  MicroSD Card Module & SPI\\
  \hline
  Accelerometer (ADXL345) &  I2C\\
  \hline
  Temperature Sensor (L535) & Single Bus \\
  \hline
  Humidity Sensor (DHT11) & Single Bus \\
  \hline
  Wi-Fi Module (ESP8266, NodeMCU 1.0) & UART \\
  \hline
 
\end{tabular}
\caption{Communication Protocols}
\end{table}

To simplify the communication protocol, after the Arduino reads all the values from the sensors it formats them into bytestring to send to either the Wi-Fi module or the PC directly via USB. The bytestring takes the form

\begin{verbatim}
(A<Sensor #><Sensor Val>,B<Sensor #><Sensor Val>,C<Sensor #><Sensor Val>)
\end{verbatim}
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

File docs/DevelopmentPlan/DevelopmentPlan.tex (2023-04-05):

\documentclass[12pt,titlepage]{article}

\usepackage{booktabs}
\usepackage{tabularx}
\usepackage{float}
\usepackage{fullpage}
\usepackage{longtable}

\date{}

\input{../Comments}
\input{../Common}

\begin{document}
\title{\huge Development Plan\\\progname}

\author{\authname}
\date{\today}

\maketitle
\newpage

\begin{table}[hp]
\caption{Revision History} \label{TblRevisionHistory}
\begin{tabularx}{\textwidth}{llX}
\toprule
\textbf{Date} & \textbf{Developer(s)} & \textbf{Change}\\
\midrule
09/25/22 & Muhanad Sada & Workflow Plan, POC Demo Plan, Technology\\
09/25/22 & Ahmed Nazir & Technology\\
04/04/23 & Muhanad Sada & Updated team roles, programming libraries, and software tools \\
04/05/23 & All & Revision 1\\
\bottomrule
\end{tabularx}
\end{table}

\newpage
\tableofcontents
\listoftables

\newpage
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

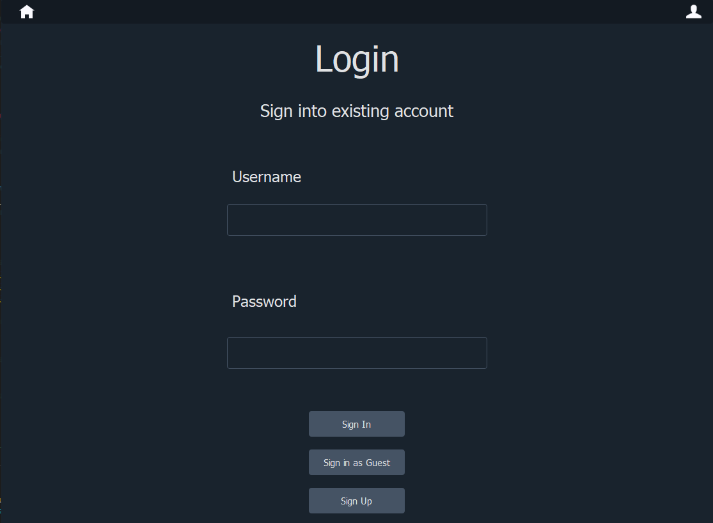
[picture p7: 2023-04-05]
docs/Design/SystDesign/login_page.png

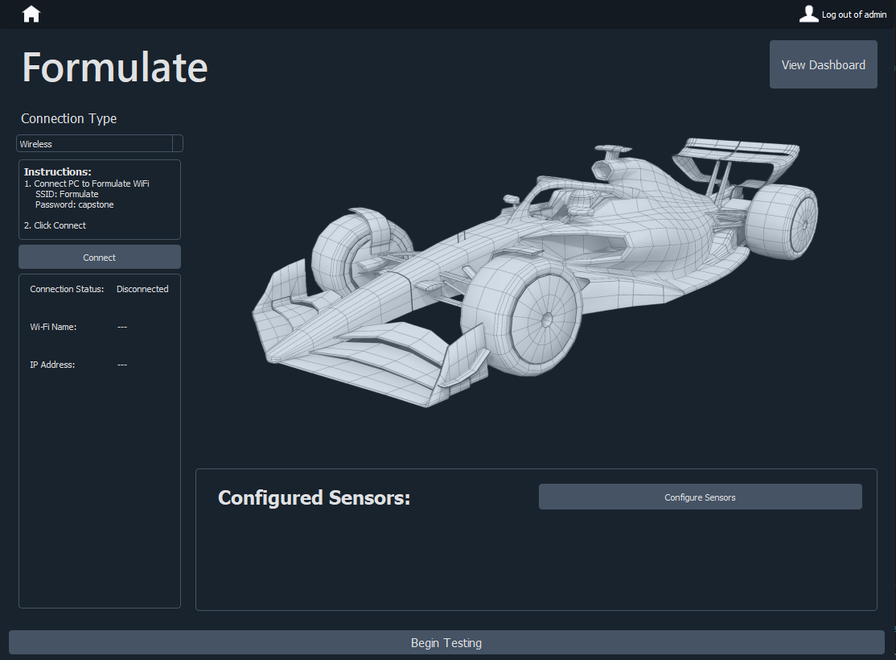
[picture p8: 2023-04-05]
docs/Design/SystDesign/home_page.png

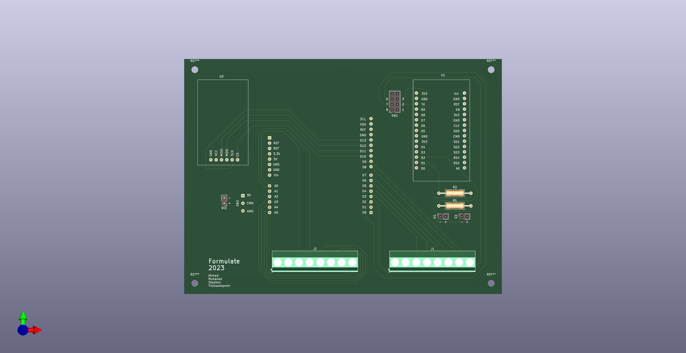
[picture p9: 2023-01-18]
docs/Design/SystDesign/PCB_Front_View.png

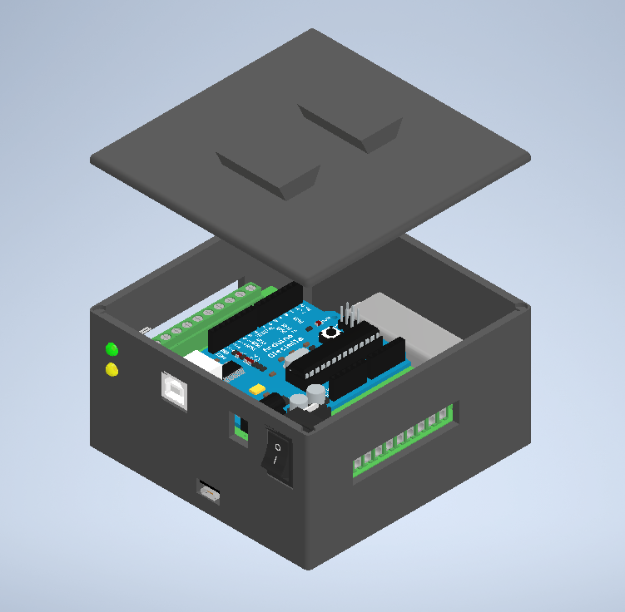
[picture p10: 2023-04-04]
docs/Design/SystDesign/Chassis_3D_Render.png

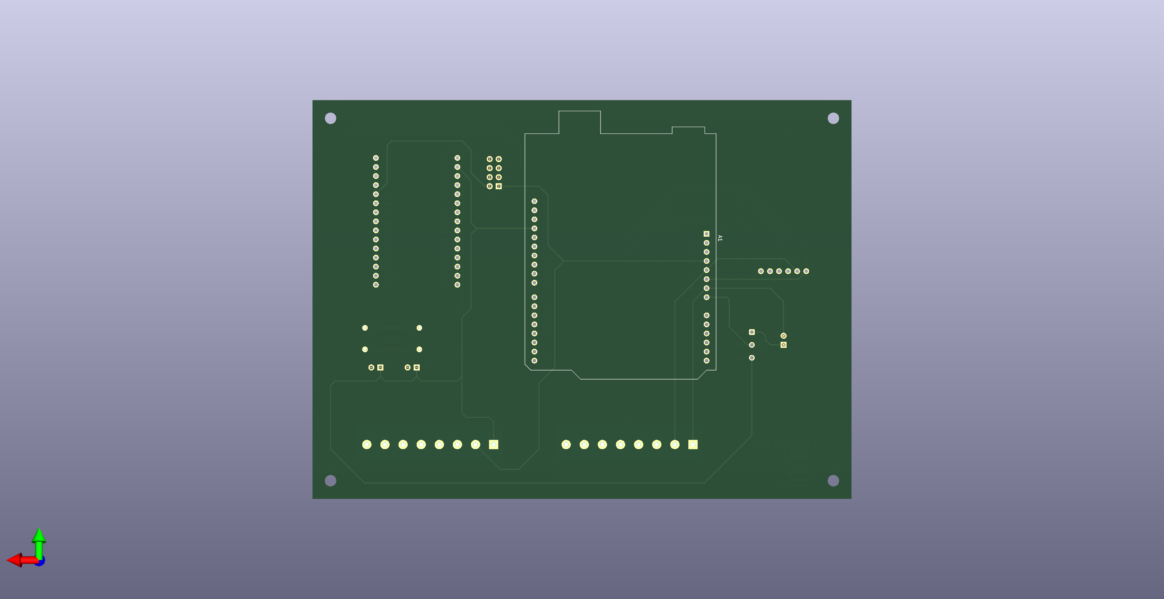
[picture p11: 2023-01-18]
docs/Design/SystDesign/PCB_Back_View.png

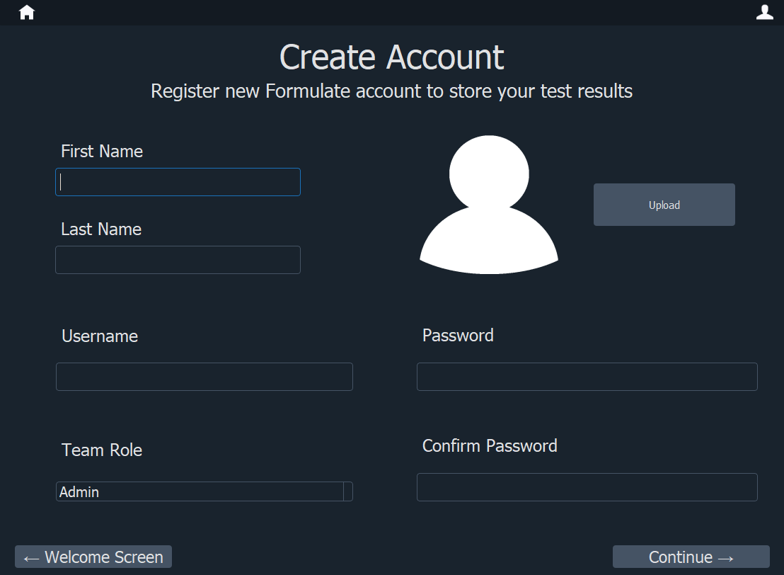
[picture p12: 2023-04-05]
docs/Design/SystDesign/signup_page.png

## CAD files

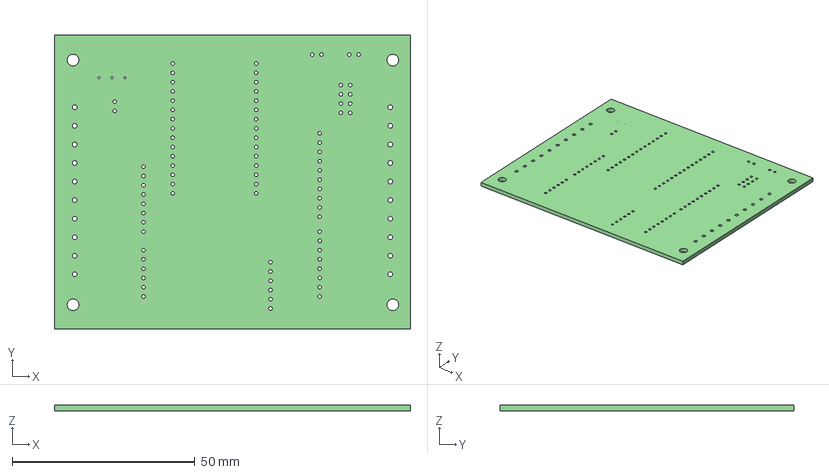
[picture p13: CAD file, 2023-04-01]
src/Chassis/REV 1/PCB REV2.step
97.5 x 80.5 x 1.60 mm

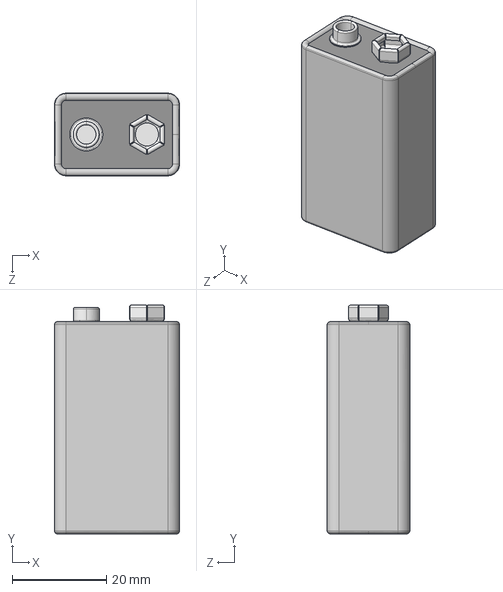
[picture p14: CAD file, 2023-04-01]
src/Chassis/REV 1/Step Files/9V Battery.STEP
26.5 x 48.5 x 17.5 mm

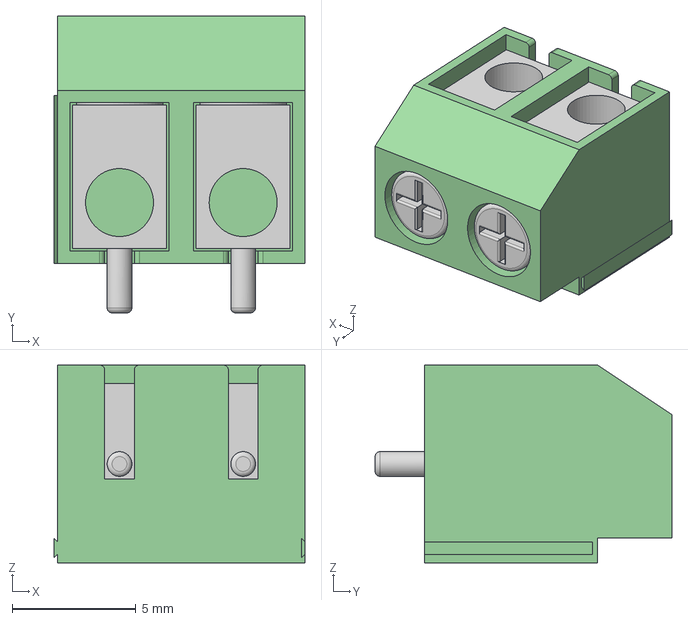
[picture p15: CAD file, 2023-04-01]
src/Chassis/REV 1/Step Files/2-Terminal Block.step
10.2 x 12.0 x 8.00 mm

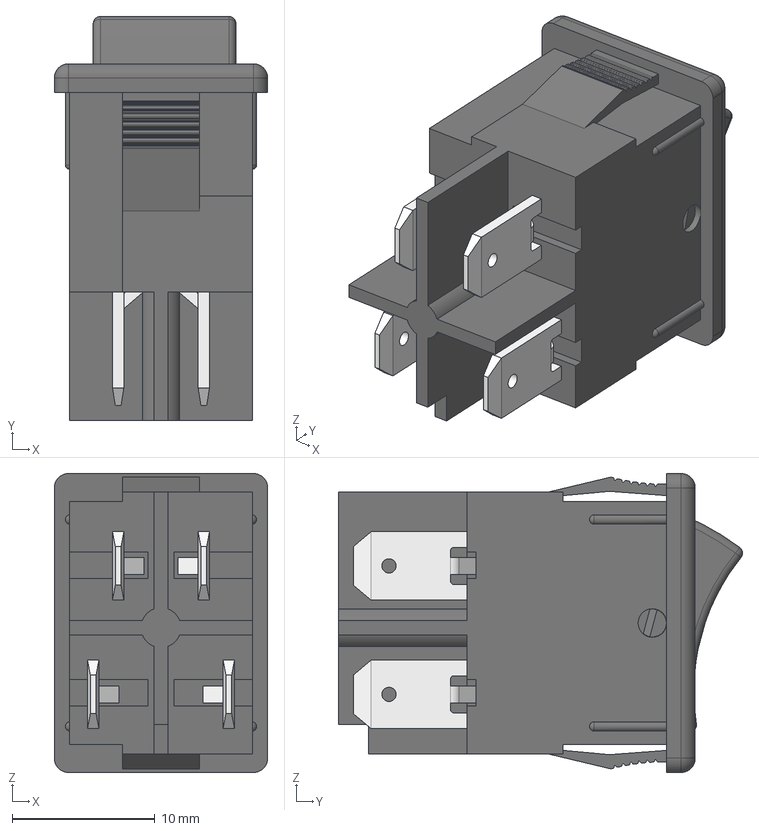
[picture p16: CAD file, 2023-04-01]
src/Chassis/REV 1/Step Files/Switch.stp
15.0 x 28.3 x 21.0 mm
Arcolectric H8550VB Rocker Switch Housing
Arcolectric H8550VB Rocker Switch Rocker
Arcolectric H8550VB Rocker Switch Terminal x 4

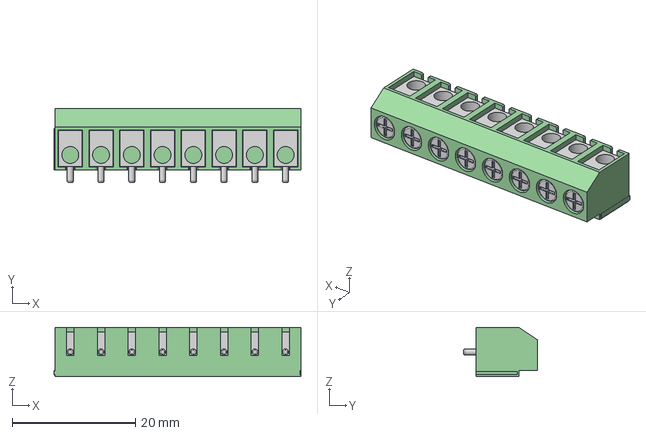
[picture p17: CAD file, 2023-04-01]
src/Chassis/REV 1/Step Files/8-Terminal Block.step
40.1 x 12.0 x 8.00 mm

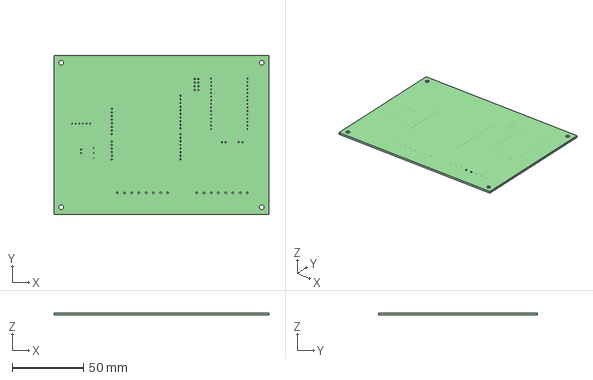
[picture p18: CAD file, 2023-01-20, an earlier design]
src/Chassis/REV 0/PCB.step
151.1 x 111.8 x 1.60 mm

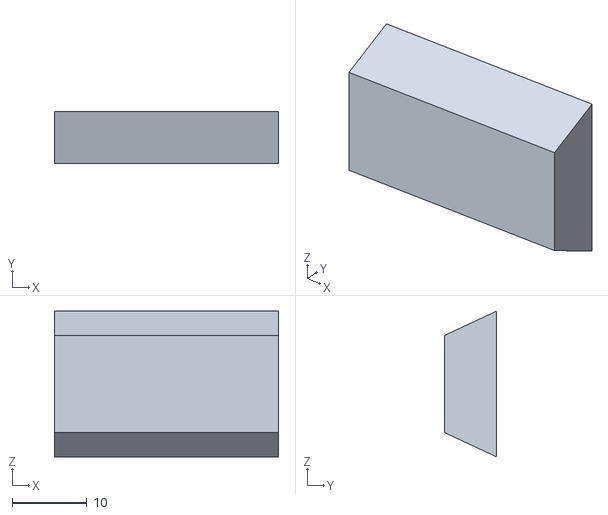
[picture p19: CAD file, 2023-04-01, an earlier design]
src/Chassis/REV 0/Sensor Mount/Bottom Sensor Mount.stl
30.0 x 7.00 x 19.5

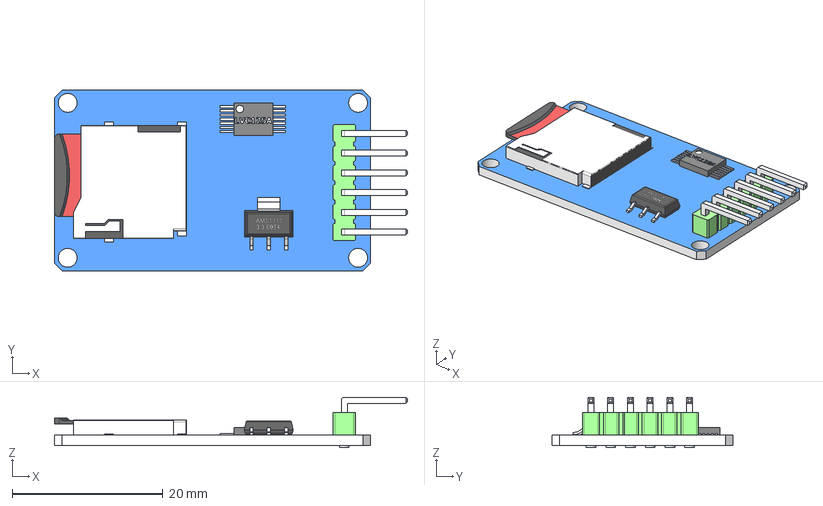
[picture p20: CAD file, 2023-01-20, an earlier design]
src/Chassis/REV 0/MicroSD Module.stp
46.9 x 24.0 x 6.70 mm
sdreader
AMS1117
card sd

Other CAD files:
src/Chassis/REV 0/Back Wall.ipt
src/Chassis/REV 0/Base Full.ipt
src/Chassis/REV 0/Base.ipt
src/Chassis/REV 0/Front Wall.ipt
src/Chassis/REV 0/Left Wall.ipt
src/Chassis/REV 0/Lid.ipt
src/Chassis/REV 0/Right Wall.ipt
src/Chassis/REV 0/SD Card Spacer.ipt
src/Chassis/REV 0/Sensor Mount/3-Pin Sensor Mount.ipt
src/Chassis/REV 0/Sensor Mount/4-Pin Sensor Mount.ipt
src/Chassis/REV 0/Sensor Mount/Bottom Sensor Mount.ipt
src/Chassis/REV 1/Base Chassis.ipt
src/Chassis/REV 1/DIN Rail Mount.ipt
src/Chassis/REV 1/Lid.ipt
src/Chassis/REV 1/Step Files/Bottom Sensor Mount.ipt
src/Chassis/REV 1/Step Files/LED - green.ipt
src/Chassis/REV 1/Step Files/LED - yellow.ipt

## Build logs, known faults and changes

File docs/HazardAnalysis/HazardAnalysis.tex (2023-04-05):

\documentclass[12pt,titlepage]{article}

\usepackage{booktabs}
\usepackage{tabularx}
\usepackage{hyperref}
\usepackage{colortbl}
\usepackage{fullpage}
\usepackage{longtable}
\newcounter{fmeanum}
\newcounter{fmeanumDA}
\newcounter{fmeanumD}
\newcounter{fmeanumDAW}
\newcounter{reqnum} %Requirement Number

\hypersetup{
    colorlinks=true,       % false: boxed links; true: colored links
    linkcolor=red,          % color of internal links (change box color with linkbordercolor)
    citecolor=green,        % color of links to bibliography
    filecolor=magenta,      % color of file links
    urlcolor=cyan           % color of external links
}

\title{\huge Hazard Analysis \\ \progname}

\author{\authname}
\date{\today}

\input{../Comments}
\input{../Common}

\begin{document}

\maketitle

\pagenumbering{roman}

\begin{table}[hp]
\caption{Revision History} \label{TblRevisionHistory}
\begin{tabularx}{\textwidth}{llX}
\toprule
\textbf{Date} & \textbf{Developer(s)} & \textbf{Change}\\
\midrule
10/12/2022 & Ahmed & Added Failure Mode and Effect Analysis\\
10/13/2022 & Stephen & Added Introduction and Scope\\
10/13/2022 & Muhanad & Added Critical Assumptions and Safety Requirements\\
10/14/2022 & Tioluwalayomi & Added System Boundaries and Roadmap\\
10/19/2022 & All & General edits\\
04/02/2023 & Ahmed & Added REV1 changes\\
\bottomrule
\end{tabularx}
\end{table}

~\newpage

\tableofcontents
\listoftables

~\newpage

\pagenumbering{arabic}

\wss{You are free to modify this template.}

\section{Introduction}

A hazard is the combination of a system property with an environmental condition that can cause harm to the intended user.\\

Hazard analysis is a critical consideration in the design of all systems. When done correctly, hazards to the end user are identified and can be mitigated or eliminated completely. While it is not possible to guarantee the safety of a system, applying hazard analysis methods is a neccesary step in supporting the safety of the system. \\

Formulate's area of work combines hardware and software sub-systems and as a result, requires hazard analysis to obtain a comprehensive understanding of the overall system. 

\wss{You can include your definition of what a hazard is here.}

\section{Scope and Purpose of Hazard Analysis}

In this document, Formulate details the hazards a user can experience through the Failure Mode and Effect Analysis method. As a result, the group systematically outlined the hazards and measures that were considered to mitigate or eliminate the hazard.

\section{System Boundaries and Components}

The device that is referred to in this document is made up of 5 major components that hazard and failure analysis would have to be done for:

\begin{enumerate}
\item Hardware
\item Desktop Application
\item Database
\item Data Dashboard 
\end{enumerate}

Each component has their own system boundaries based on the software and hardware we use. Since this is the case we will have to design the system based on the type of the test that is required to be performed by the MAC Formula Electric Team. An example of this would be if the client had to test the car under specific conditions, we would choose hardware components that are within that temperature range to ensure data is read correctly.

\newpage
\section{Critical Assumptions}

\begin{itemize}
	\item The user understands the safety precautions of operating and working with a Formula Electric vehicle
	\item The user has a basic understanding of handling electrical and mechanical components
	\item The user aims to always correctly operate the testing device
\end{itemize}

\wss{These assumptions that are made about the software or system.  You should
minimize the number of assumptions that remove potential hazards.  For instance,
you could assume a part will never fail, but it is generally better to include
this potential failure mode.}

\newpage
\section{Failure Mode and Effect Analysis}
\begin{longtable}{| p{0.14\textwidth} | p{0.04\textwidth}| p{0.15\textwidth}| p{0.20\textwidth}| p{0.20\textwidth}| p{0.18\textwidth}|}
    \hline
    \rowcolor[gray]{0.9}
    \textbf{Component} 
    & \textbf{Ref}
    & \textbf{Failure Mode}
    & \textbf{Effects of Failure} 
    & \textbf{Cause of Failure}
    & \textbf{Recommended Actions} \\
    %Component & Ref & Failure Mode & Effects of Failure & Cause of Failure & Recommended Actions\\
    \hline 
    Hardware & H1.\refstepcounter{fmeanum}\thefmeanum
    & Connection Failure
    & Test data is not captured by our PC
    &   $\bullet$ The Wi-Fi module is broken \newline
        $\bullet$ USB Device is not connected to PC \newline
        $\bullet$ PC is not connected to the device Wi-Fi \newline 
    & Using the device's yellow LED to convey the system's connectivity \\
    \cline{2-6}
        & H1.\refstepcounter{fmeanum}\thefmeanum
    & System does not have power
    & Device is off and not operational
    &   $\bullet$ Battery died \newline
        $\bullet$ Power cables are disconnected \newline
        $\bullet$ Too much current is drawn from Arduino \newline 
    & $\bullet$ Add a Power indicator to the device to alert the user if the device has power \newline
      $\bullet$ Make the sensors get their power directly from the power source and not the Arduino \newline \\

    \cline{2-6}
        & H1.\refstepcounter{fmeanum}\thefmeanum
    & Hardware falls off the mount
    &   $\bullet$ Hardware device breaks/gets damaged \newline
        $\bullet$ Sensors capture incorrect data \newline
        $\bullet$ Potential injury to those in vehicle \newline
    &  $\bullet$ User didn’t affix hardware properly \newline
       $\bullet$ Mounting mechanism failed \newline
    & The mounting mechanism should give the user physical feedback when the device is mounted correctly\\

    \hline
    Desktop \space Application & H2.\refstepcounter{fmeanumDA}\thefmeanumDA
    & Application cannot read hardware device output
    & Refer to H1.1
    & $\bullet$ Refer to H1.1 \newline
      $\bullet$ COM Port is being used by another application \newline
    &Ensure that the COM port is open for communication\\

    \cline{2-6}
     & H2.\refstepcounter{fmeanumDA}\thefmeanumDA
    & Data from the hardware device is lost
    & Test results will all be lost
    & $\bullet$ Application suddenly closes during test \newline
      $\bullet$ Hardware device disconnects from PC \newline
    &Store last test data into local storage\\

    \cline{2-6}
     & H2.\refstepcounter{fmeanumDA}\thefmeanumDA
    & Cannot view live data
    & User will not be able to see live data during test runs
    & $\bullet$ Refer to H2.1\newline
      $\bullet$ Refer to H1.1 \newline
    & Device will default to record the entire test run and save the test data into local storage\\

    \cline{2-6}
     & H2.\refstepcounter{fmeanumDA}\thefmeanumDA
    & Data cannot be sent to database
    & Test results will not be saved to the database and will not be viewable in the analytics platform
    & $\bullet$ Database failure \newline
      $\bullet$ Connection failure between Desktop App and Database  \newline
      $\bullet$ PC not connected to the internet \newline
    &Verify that user's PC is connected to the internet, and ensure that application can connect to database\\

    \hline

    Database & H3.\refstepcounter{fmeanumD}\thefmeanumD
    & Database Overload
    & The database is getting overloaded with data causing it to crash or freeze
    & User submits too much data within a very short time period
    & Add a cool down timer after the user submits the data to the database so they will not be able to spam test submissions\\
    \hline

    Data \newline Dashboard & H4.\refstepcounter{fmeanumDAW}\thefmeanumDAW
    & User cannot login
    & User will not have access to dashboard
    & $\bullet$ User does not have an account \newline
      $\bullet$ User’s credentials do not match \newline
    &Redirect user to either create a new login or to reset their login\\
    \cline{2-6}

    & H4.\refstepcounter{fmeanumDAW}\thefmeanumDAW
    & User cannot view the dashboard
    & Users cannot view KPIs of tests
    & $\bullet$ User does not have required permissions \newline
    &User can request permission which needs to be approved by an admin\\
    \cline{2-6}

    & H4.\refstepcounter{fmeanumDAW}\thefmeanumDAW
    & Data is not displayed on the dashboard
    & Refer to H4.2
    & $\bullet$ Database does not contain test data \newline
    $\bullet$ Authentication error \newline
    &Validate connection between dashboard and database, and ensure database contains data\\
    \hline

  \caption{Failure Mode and Effect Analysis}
    \end{longtable}

\wss{Include your FMEA table here}

\section{Safety and Security Requirements}

\begin{itemize}
  \item[SR \refstepcounter{reqnum}\thereqnum:] The device should verify a connection between sensors, device, and application before starting measurements.
    \begin{description} \item[Rationale] If the connections are not verified, then data might be lost as it never gets send to either the device, application and/or database.  \end{description}
    \begin{description} \item[Associated Hazards] H1.1, H2.1, H2.2, H2.3, H2.4  \end{description}
  
  \item[SR \refstepcounter{reqnum}\thereqnum:] The device should have a power LED indicating to the user if the battery is working.
    \begin{description} \item[Rationale] If the battery dies during testing, measurement values will be lost as it is the power source of the device.  \end{description}
    \begin{description} \item[Associated Hazards] H1.2  \end{description}

  \item[SR \refstepcounter{reqnum}\thereqnum:] Every user should have a login when accessing the data dashboard.
    \begin{description} \item[Rationale] This ensures that only testers have view access to values on the dashboard.   \end{description}
    \begin{description} \item[Associated Hazards] H4.1, H4.2, H4.3 \end{description}
  
  \item[SR \refstepcounter{reqnum}\thereqnum:] The device should save a certain amount of values in case the connection to the application fails during testing.
    \begin{description} \item[Rationale] This ensures that the most recent data is not lost if there is a connection failure.   \end{description}
    \begin{description} \item[Associated Hazards] H1.1, H2.2  \end{description}
  
  \item[SR \refstepcounter{reqnum}\thereqnum:] The device should have an audible click to indicate that the device and sensors have mounted correctly.
    \begin{description} \item[Rationale] The audible click aids the user in mounting the hardware correctly to ensure that it does not fall off.   \end{description}
    \begin{description} \item[Associated Hazards] H1.3  \end{description}
\end{itemize}

\wss{Newly discovered requirements.  These should also be added to the SRS.  (A
rationale design process how and why to fake it.)}

\section{Roadmap}

These requirements will be implemented during the course of the capstone. The safety and security requirements are important for a complete and safe testing device. Due to the time constraint we face, some requirements will take priority over others. Over the course of our capstone we will continuously update this document with any other hazards that might arise. We aim to mitigate all the hazards by the end of the term.

\end{document}

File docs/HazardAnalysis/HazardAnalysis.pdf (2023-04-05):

# Hazard Analysis Formulate

### Team 25, MECHTRON 4TB6 Ahmed Nazir, nazira1 Stephen Oh, ohs9 Muhanad Sada, sadam Tioluwalayomi Babayeju, babayejt

### April 5, 2023

Table 1: Revision History
Date | Developer(s) Change
10/12/2022 Ahmed | Added Failure Mode and Effect Analysis
10/13/2022 Stephen | Added Introduction and Scope
10/13/2022 Muhanad | Added Critical Assumptions and Safety Requirements
10/14/2022 Tioluwalayomi Added System Boundaries and Roadmap
10/19/2022 All | General edits
04/02/2023 Ahmed | Added REV1 changes

i

## Contents

1 Introduction | 1
2 Scope and Purpose of Hazard Analysis | 1
3 System Boundaries and Components | 1
4 Critical Assumptions | 2
5 Failure Mode and Effect Analysis | 3
6 Safety and Security Requirements | 5
7 Roadmap | 6

## List of Tables

ii

## 1 Introduction

A hazard is the combination of a system property with an environmental condition that can cause harm to the intended user.

Hazard analysis is a critical consideration in the design of all systems. When done correctly, hazards to the end user are identified and can be mitigated or eliminated completely. While it is not possible to guarantee the safety of a system, applying hazard analysis methods is a neccesary step in supporting the safety of the system.

Formulate’s area of work combines hardware and software sub-systems and as a result, requires hazard analysis to obtain a comprehensive understanding of the overall system.

## 2 Scope and Purpose of Hazard Analysis

In this document, Formulate details the hazards a user can experience through the Failure Mode and Effect Analysis method. As a result, the group systematically outlined the hazards and measures that were considered to mitigate or eliminate the hazard.

## 3 System Boundaries and Components

The device that is referred to in this document is made up of 5 major components that hazard and failure analysis would have to be done for:

1. Hardware
2. Desktop Application
3. Database
4. Data Dashboard

Each component has their own system boundaries based on the software and hardware we use. Since this is the case we will have to design the system based on the type of the test that is required to be performed by the MAC Formula Electric Team. An example of this would be if the client had to test the car under specific conditions, we would choose hardware components that are within that temperature range to ensure data is read correctly.

1

## 4 Critical Assumptions

| The user understands the safety precautions of operating and working with a Formula Electric vehicle
| The user has a basic understanding of handling electrical and mechanical components
| The user aims to always correctly operate the testing device

2

## 5 Failure Mode and Effect Analysis

Component | Ref | Failure Mode | Effects of Fail-ure | Cause of Failure | Recommended Actions
| | Failure | Test data is not captured by our PC | • The Wi-Fi mod-ule is broken • USB Device is not connected to PC • PC is not con-nected to the de-vice Wi-Fi | Using the de-vice’s yellow LED to convey the system’s connectivity
| H1.2 | System does not have power | Device is off and not operational | • Battery died • Power cables are disconnected • Too much cur-rent is drawn from Arduino | • Add a Power indicator to the device to alert the user if the device has power • Make the sensors get their power directly from the power source and not the Arduino
| H1.3 | Hardware falls off the mount | • Hardware device breaks/gets dam-aged • Sensors capture incorrect data • Potential injury to those in vehicle | • User didn’t affix hardware properly • Mounting mech-anism failed | The mounting mechanism should give the user phys-ical feedback when the device is mounted correctly
| H2.1 | Application cannot read hardware device output | Refer to H1.1 | • Refer to H1.1 • COM Port is be-ing used by an-other application | Ensure that the COM port is open for communication
Hardware | H1.1 | Connection

Desktop
Application

3

H2.2 | Data | from
the hardware
device is lost

Test results will all
be lost
- Application suddenly closes during test
- Hardware device
disconnects from
PC

Store last test
data into local
storage
H2.3 | Cannot view live data | User will not be able to see live data during test runs | • Refer to H2.1 • Refer to H1.1 | Device will de-fault to record the entire test run and save the test data into lo-cal storage
H2.4 | Data cannot be sent to database | Test results will not be saved to the database and will not be view-able in the analyt-ics platform | • Database failure • Connection failure between Desktop App and Database • PC not con-nected to the internet | Verify that user’s PC is connected to the internet, and ensure that application can connect to database
Database | H3.1 | Database Overload | The database is getting overloaded with data caus-ing it to crash or freeze | User submits too much data within a very short time period | Add a cool down timer after the user submits the data to the database so they will not be able to spam test submissions
| H4.1 | User cannot login | User will not have access to dashboard | • User does not have an account • User’s creden-tials do not match | Redirect user to either create a new login or to reset their login
| H4.2 | User cannot view the dashboard | Users cannot view KPIs of tests | • User does not have required per-missions | User can request permission which needs to be approved by an admin

Data
Dashboard

4

H4.3 Data is not
displayed on
the dashboard
Refer to H4.2 | • Database does
not contain test
data
- Authentication
error

Validate connection between
dashboard and
database, and
ensure database
contains data
Table 2: Failure Mode and Effect Analysis

## 6 Safety and Security Requirements

SR 1: The device should verify a connection between sensors, device, and application before starting measurements.

Rationale If the connections are not verified, then data might be lost as it never gets send to either the device, application and/or database.

Associated Hazards H1.1, H2.1, H2.2, H2.3, H2.4

SR 2: The device should have a power LED indicating to the user if the battery is working.

Rationale If the battery dies during testing, measurement values will be lost as it is the power source of the device.

Associated Hazards H1.2

SR 3: Every user should have a login when accessing the data dashboard.

Rationale This ensures that only testers have view access to values on the dashboard.

Associated Hazards H4.1, H4.2, H4.3

SR 4: The device should save a certain amount of values in case the connection to the application fails during testing.

Rationale This ensures that the most recent data is not lost if there is a connection failure.

Associated Hazards H1.1, H2.2

SR 5: The device should have an audible click to indicate that the device and sensors have mounted correctly.

Rationale The audible click aids the user in mounting the hardware correctly to ensure that it does not fall off.

Associated Hazards H1.3

5

## 7 Roadmap

These requirements will be implemented during the course of the capstone. The safety and security requirements are important for a complete and safe testing device. Due to the time constraint we face, some requirements will take priority over others. Over the course of our capstone we will continuously update this document with any other hazards that might arise. We aim to mitigate all the hazards by the end of the term.

6

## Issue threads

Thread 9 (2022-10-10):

Team 25 Review - Improving verifiability of requirements

RutheniumVI, 2022-10-10:
Some of the requirements either need to be rephrased to be more verifiable or a fit criterion should be described. One such example of requirement is FR8, which describes that "The device should easily mount ", where it is hard to verify what "easily" means. A fit criterion might be helpful in this case.  More occurences of these happened for you NFR too, which is pretty common when constructing NFRs because they can be subjective. A fit criterion like user survey would be greatly beneficial in those cases.

Having verifiable requirement will be helpful for you to conclude on whether you successfully achieved your requirement or not. We do not want to end up being lost trying to figure out when we reached our goal when we might be past it.

RutheniumVI, 2022-10-10:
@samm82

Closed 2023-04-06.

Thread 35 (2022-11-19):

[FEAT] - Hardware prototype to process Live Data

stoh1729, 2022-11-19:
Demonstrate live data capability via building a non-permanent setup using the breadboard and required components

Required components:
-Wireless communication: Wi-fi module
-Embedded board power: Battery
-Local data storage for wireless com failure: SD card + SD card module

Some steps that will likely need to occur:
-Select+purchase specific models from Amazon for the hardware outlined above
-Write an Arduino module to communicate with the Desktop App via wi-fi module
-Write an Arduino module to save live test data to SD

stoh1729, 2022-11-19:
Split up into 3 different tasks based on hardware.

stoh1729, 2022-11-19:
Ahmed: Wi-fi, Mo: SD Card, Stephen: Battery

Closed 2023-02-22.

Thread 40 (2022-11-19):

[FEAT] - Chassis for hardware

stoh1729, 2022-11-19:
Once size of electrical components such as modules required for live data processing + PCB is determined, design + CAD + 3D print the chassis.

Could be important to think about how we can have a reliable chassis opening mechanism specifically.

Closed 2023-02-22.

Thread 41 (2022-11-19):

[FEAT] - Abstracting sensors

stoh1729, 2022-11-19:
It would be nice if users did not have to think about how to connect a sensor from the market to our embedded device.

To do this, the sensor connections need to be abstracted by creating classes of sensors (such as 3 wire, 4 wire, etc.), and then design + CAD + 3D print hardware that supports this abstraction.

It could look similar to a something used in industrial hardware, where the connection is guided and the user does not necessarily need to know what each of the pins do in order to successfully connect the cable.

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

ahmed-nazir, 2023-02-22:
We used JST connectors

Closed 2023-02-22.

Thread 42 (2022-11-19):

[FEAT] - Sensor calibration

stoh1729, 2022-11-19:
User should be able to calibrate the sensor voltage to physical measurement reading in the desktop app.

Closed 2023-04-06.

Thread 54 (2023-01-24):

[FEAT] - Modularize Arduino code

muhanadsada, 2023-01-24:
**Describe the solution you'd like**
Modularize code to easily add/remove new sensors

**Describe alternatives you've considered**
A clear and concise description of any alternative solutions or features you've considered.

**Additional context**
Add any other context or screenshots about the feature request here.

ahmed-nazir, 2023-02-22:
Separated each sensor into a header (.h) file

Closed 2023-02-22.

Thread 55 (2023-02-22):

[FEAT] - Code Generator

ahmed-nazir, 2023-02-22:
Create a code generator for the Arduino to adjust bytestring of currently implemented sensors

ahmed-nazir, 2023-02-22:
Create a UI page for selecting sensors

Closed 2023-04-02.

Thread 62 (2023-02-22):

[BUG] - PowerBi Filter include date and test name in filter selection

ahmed-nazir, 2023-02-22:
When the user selects which test to see they should see the date and the name of the test in the drop down

Closed 2023-04-06.

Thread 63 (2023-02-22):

[BUG] - Wireless Auto connect/disconnect to Wifi

ahmed-nazir, 2023-02-22:
When testing thru wireless the device should automatically connect to wifi and disconnect to wifi when submitting data to the database

Closed 2023-04-02.

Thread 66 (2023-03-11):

Team 18 Review: VnVReport Missing Usability Survey Results

billsong0407, 2023-03-11:
The report is well written! In the VnV Plan, your team included a usability survey, and ST-U1, ST-U2, ST-U3 will be conducted on a group of users. However, I do not see any survey results included in the report. Another recommendation is to indicate the number of users participated in ST-U 1-A and ST-U 1-B (the legend on the x-axis is confusing).

Closed 2023-04-06.

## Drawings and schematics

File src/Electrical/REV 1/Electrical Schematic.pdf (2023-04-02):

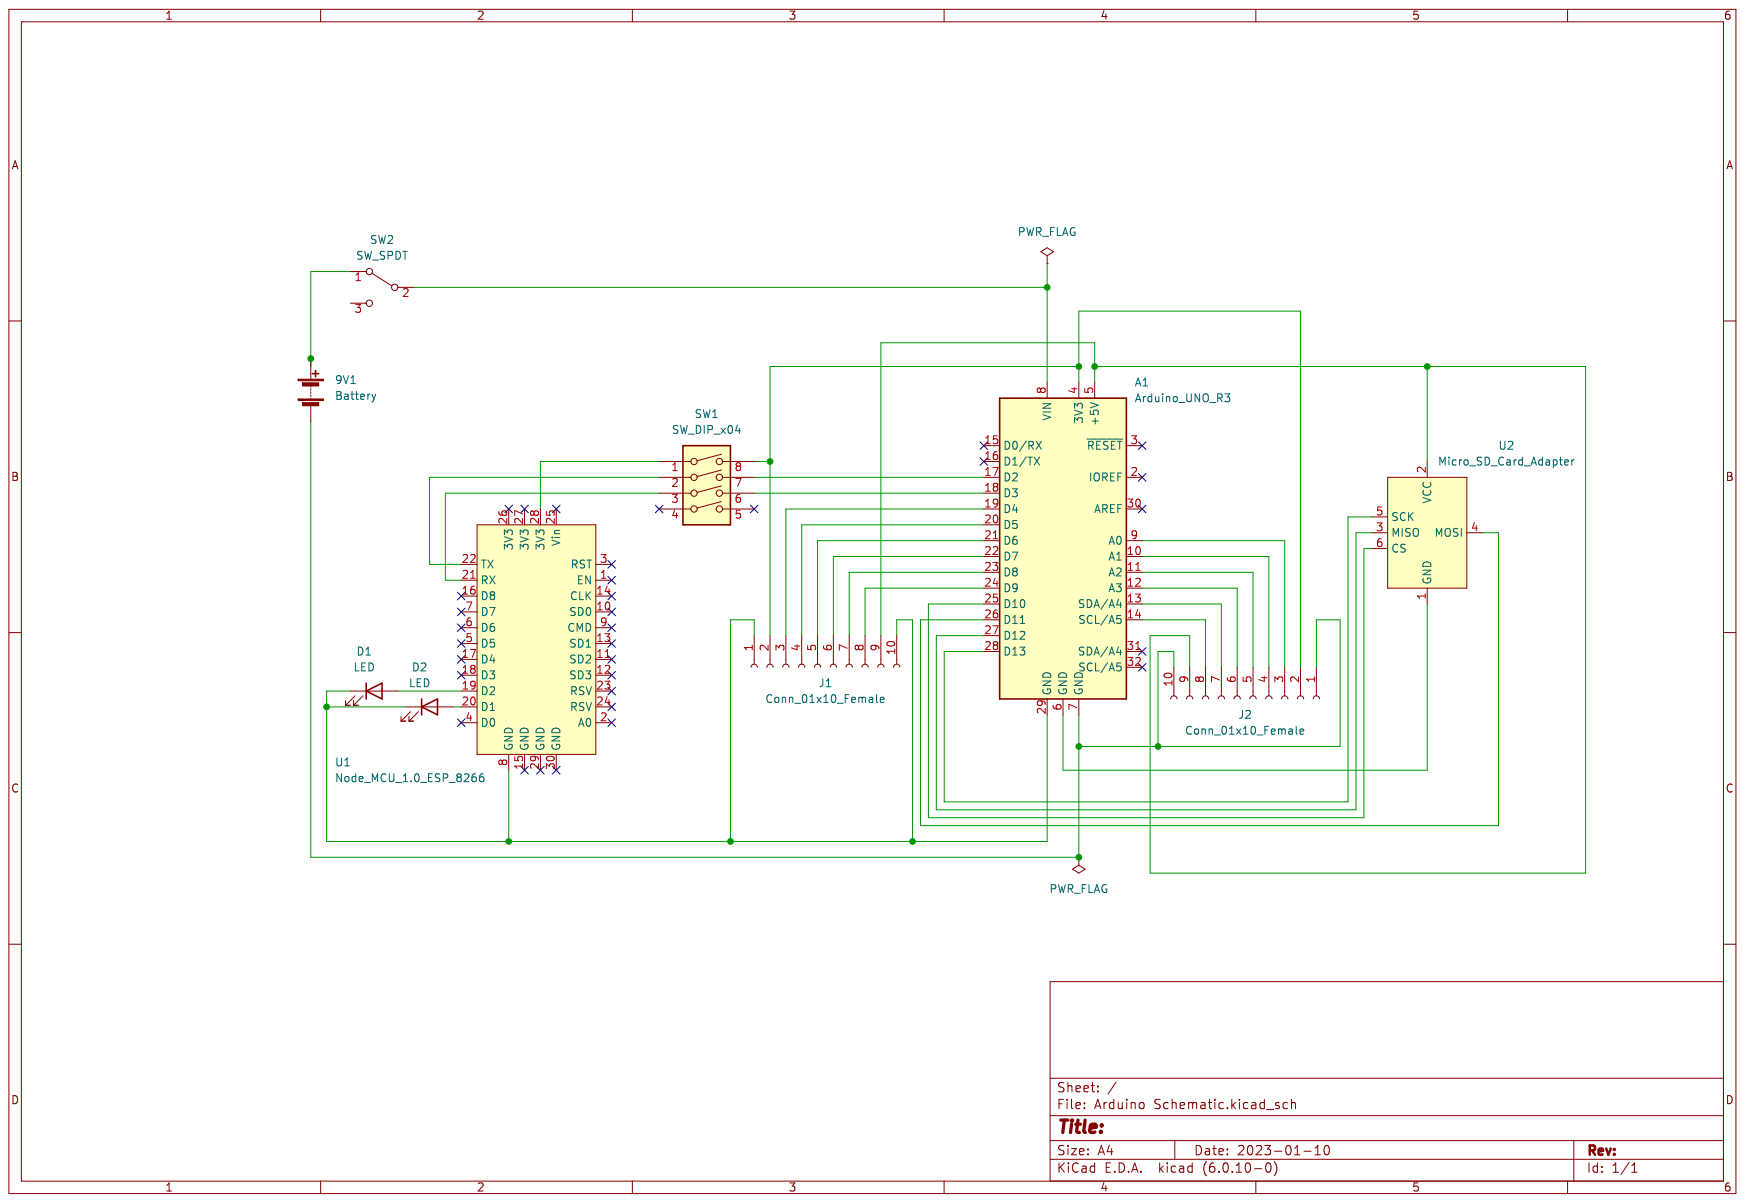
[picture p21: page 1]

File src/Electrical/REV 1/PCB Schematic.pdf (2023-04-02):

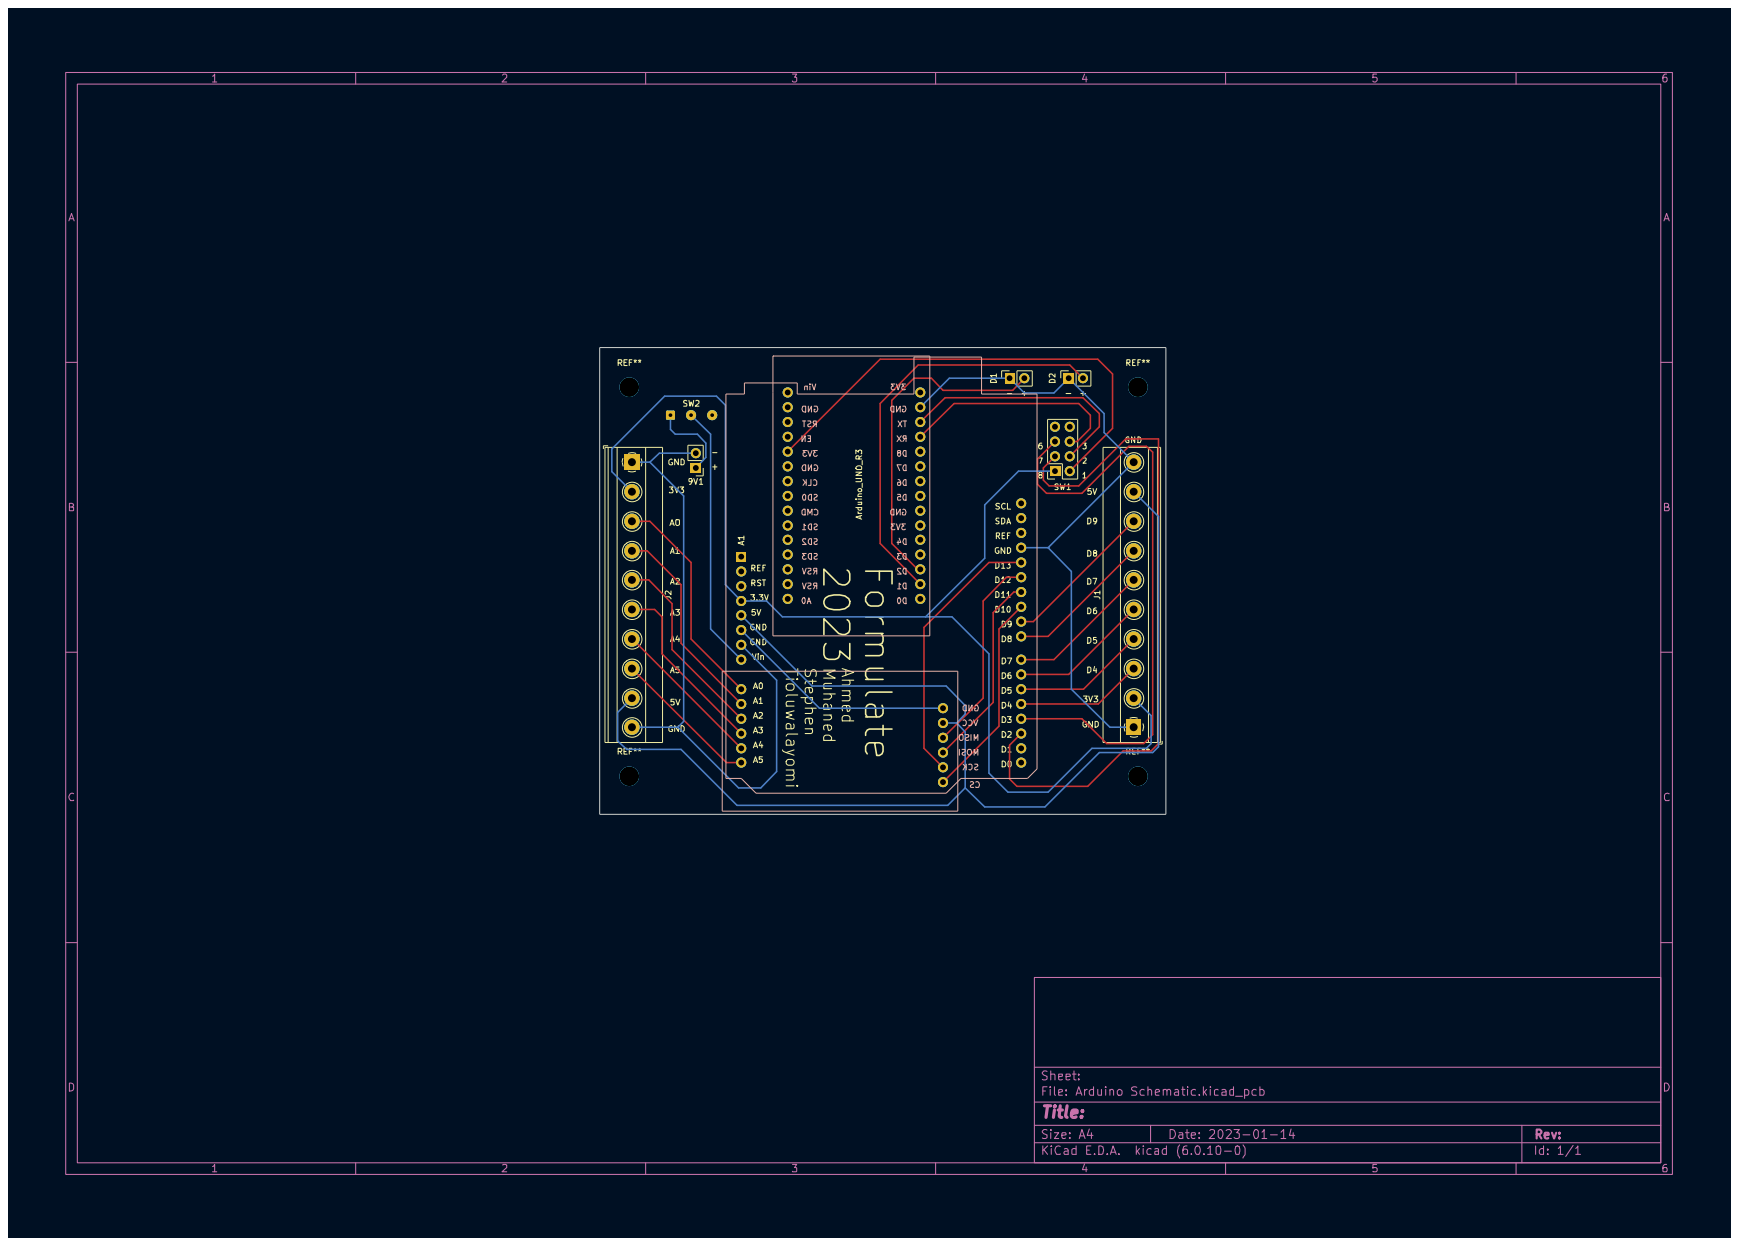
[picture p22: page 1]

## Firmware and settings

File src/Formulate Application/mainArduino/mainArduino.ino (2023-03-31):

#include <SoftwareSerial.h>
#include <SPI.h>
#include <SD.h>
#include "ADXL345_1.h"
#include "LM35_1.h"

File myFile;
SoftwareSerial espSerial(2,3);

const int chipSelect = 10;

int wiredSend = 0;
int wifiSend = 0;
int wiredRead;
int wifiRead;

float AccelerationX1;
float AccelerationY1;
float AccelerationZ1;
float Temperature1;

void readData(){
  ADXL345_1_SensorValues ADXL345_1_Values = readADXL345_1();
  LM35_1_SensorValues LM35_1_Values = readLM35_1(3);
  AccelerationX1 = ADXL345_1_Values.A;
  AccelerationY1 = ADXL345_1_Values.B;
  AccelerationZ1 = ADXL345_1_Values.C;
  Temperature1 = LM35_1_Values.A;
}
void setup() {
  Serial.begin(9600);
  espSerial.begin(9600);
  SD.begin();

  setupADXL345_1();
  setupLM35_1(3);
}

void loop() {
  // === Start and Stop Wireless Serial Comm === //
  wifiRead = espSerial.read();
  if(wifiRead == 81){
    wifiSend = 1;
    SD.remove("TestData.txt");
    myFile = SD.open("TestData.txt", FILE_WRITE);
    if (myFile) {
      myFile.close();
     }
  }
  if(wifiRead == 87){
    wifiSend = 0;
  }

  if(wifiSend){
    readData();

    // === Send Bytestring to Serial Port === //
    espSerial.print('(');
    espSerial.print('A');
    espSerial.print(1);
    espSerial.print(AccelerationX1);
    espSerial.print(',');
    espSerial.print('B');
    espSerial.print(1);
    espSerial.print(AccelerationY1);
    espSerial.print(',');
    espSerial.print('C');
    espSerial.print(1);
    espSerial.print(AccelerationZ1);
    espSerial.print(',');
    espSerial.print('D');
    espSerial.print(1);
    espSerial.print(Temperature1);
    espSerial.println(')');

    // === Write Data to SD Card === //
    myFile = SD.open("TestData.txt", FILE_WRITE);
    if (myFile) {
      myFile.print('(');
      myFile.print('A');
      myFile.print(1);
      myFile.print(AccelerationX1);
      myFile.print(',');
      myFile.print('B');
      myFile.print(1);
      myFile.print(AccelerationY1);
      myFile.print(',');
      myFile.print('C');
      myFile.print(1);
      myFile.print(AccelerationZ1);
      myFile.print(',');
      myFile.print('D');
      myFile.print(1);
      myFile.print(Temperature1);
      myFile.println(')');
      myFile.close();
    }
    delay(1100);
  }


  // === Start and Stop Wired Serial Comm === //
  wiredRead = Serial.read();
  if(wiredRead == 'G'){
    wiredSend = 1;
    SD.remove("TestData.txt");
    myFile = SD.open("TestData.txt", FILE_WRITE);
    if (myFile) {
      myFile.close();
     }
  }
  if(wiredRead == 'P'){
    wiredSend = 0;
  }
  if(wiredRead =='R'){
    myFile = SD.open("TestData.txt");
    if (myFile){
      while (myFile.available()){
        Serial.write(myFile.read());
      }
    myFile.close();
    }
  }

  if(wiredSend){
    readData();

    // === Send Bytestring to Serial Port === //
    Serial.print('(');
    Serial.print('A');
    Serial.print(1);
    Serial.print(AccelerationX1);
    Serial.print(',');
    Serial.print('B');
    Serial.print(1);
    Serial.print(AccelerationY1);
    Serial.print(',');
    Serial.print('C');
    Serial.print(1);
    Serial.print(AccelerationZ1);
    Serial.print(',');
    Serial.print('D');
    Serial.print(1);
    Serial.print(Temperature1);
    Serial.println(')');

    // === Write Data to SD Card === //
    myFile = SD.open("TestData.txt", FILE_WRITE);
    if (myFile) {
      myFile.print('(');
      myFile.print('A');
      myFile.print(1);
      myFile.print(AccelerationX1);
      myFile.print(',');
      myFile.print('B');
      myFile.print(1);
      myFile.print(AccelerationY1);
      myFile.print(',');
      myFile.print('C');
      myFile.print(1);
      myFile.print(AccelerationZ1);
      myFile.print(',');
      myFile.print('D');
      myFile.print(1);
      myFile.print(Temperature1);
      myFile.println(')');
      myFile.close();
    }
    delay(1100);
  }
}

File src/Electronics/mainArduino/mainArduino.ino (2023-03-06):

#include <SoftwareSerial.h>
#include <SPI.h>
#include <SD.h>

#include "temperatureModule.h"
#include "humidityModule.h"
#include "accelerometerModule.h"

File myFile;
SoftwareSerial espSerial(2,3);

const int chipSelect = 10;

int wiredSend = 0;
int wifiSend = 0;
int wiredRead;
int wifiRead;

#define HEADER "AccelerationX1,AccelerationY1,AccelerationZ1,Temperature1,Humidity1"
#define dataString String(X_out) + "," + String(Y_out) + "," + String(Z_out) + "," + String(temperature) + "," + String(humidity)



void readData(){
  readAccelerometer();
  readTemp();
  readHumidity();
}

void setup() {
  
  Serial.begin(9600);
  espSerial.begin(9600);
  SD.begin();
  
  setupTemp();
  setupHumidity();
  setupAccelerometer();

}

void loop() {

  // === Start and Stop Wireless Serial Comm === //
  wifiRead = espSerial.read();
  if(wifiRead == 81){
    wifiSend = 1;
    SD.remove("TestData.csv");
    myFile = SD.open("TestData.csv", FILE_WRITE);
    if (myFile) {
      String Headers = HEADER;
      myFile.println(Headers);
      myFile.close();
    }
  }
  if(wifiRead == 87){
    wifiSend = 0;
  }
  
  if(wifiSend){

    readData();
   

    // === Send Bytestring to Serial Port === //
    espSerial.print('(');
    espSerial.print('A');
    espSerial.print(1);           
    espSerial.print(X_out);
    espSerial.print(',');
    espSerial.print('B');
    espSerial.print(1); 
    espSerial.print(Y_out);
    espSerial.print(',');
    espSerial.print('C');
    espSerial.print(1); 
    espSerial.print(Z_out);
    espSerial.print(',');
    espSerial.print('D');
    espSerial.print(1); 
    espSerial.print(temperature);
    espSerial.print(',');
    espSerial.print('E');
    espSerial.print(1); 
    espSerial.print(humidity);
    espSerial.println(')');

    // === Write Data to SD Card === //
    myFile = SD.open("TestData.csv", FILE_WRITE);
    if (myFile) {
      String dataValues = dataString;
      myFile.println(dataValues);
      myFile.close();
    } 
    
    delay(1100);
    
  }
  
  
  
  // === Start & Stop Wired Serial Comm === //
  wiredRead = Serial.read();
  if(wiredRead == 'G'){
    wiredSend = 1;
    SD.remove("TestData.csv");
    myFile = SD.open("TestData.csv", FILE_WRITE);
    if (myFile) {
      String Headers = HEADER;
      myFile.println(Headers);
      myFile.close();
    }
  }
  else if(wiredRead == 'P'){
    wiredSend =0;
  }
  
  if(wiredSend){
    readData();
  
    // === Send Bytestring to Serial Port === //
    Serial.print('(');
    Serial.print('A');
    Serial.print(1);           
    Serial.print(X_out);
    Serial.print(',');
    Serial.print('B');
    Serial.print(1); 
    Serial.print(Y_out);
    Serial.print(',');
    Serial.print('C');
    Serial.print(1); 
    Serial.print(Z_out);
    Serial.print(',');
    Serial.print('D');
    Serial.print(1); 
    Serial.print(temperature);
    Serial.print(',');
    Serial.print('E');
    Serial.print(1); 
    Serial.print(humidity);
    Serial.println(')');

   // === Write Data to SD Card === //
    myFile = SD.open("TestData.csv", FILE_WRITE);
    if (myFile) {
      String dataValues = dataString;
      myFile.println(dataValues);
      myFile.close();
    } 
    
    delay(1100); //Speed of transmission
  }
}

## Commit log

2022-11-02 Doc: #25 Updated traceability table
2022-11-11 Desktop App UI+Functionality Update
    Integrated drop-down function, dynamic connection, button functionality, COM, start/stop
2022-11-13 Desktop App Functionality Update
    Added comboBox COM port refresh when button is pressed and sets program variable equal to desired COM port
2022-11-13 Added functionality to decline button
2022-12-26 Updated main.py to include accelerometer data in table
2022-12-26 Updated mainArduino.ino to read from the accelerometer
2023-01-05 Added ESP8266 wireless module
    This module transmit data from our PC to the Arduino via WiFi. It is loaded onto the ESP8266 board
2023-01-12 Updated mainESP8266 to be an access point
    Instead of connecting to a WiFi network, the board now acts like an access point
2023-01-12 Updated mainArduino.ino to include DHT11 sensor readings, Added SD Card writing and fixed wired serial comm
    [mainArduino.ino]
2023-01-17 Development
    Electrical changes: Added schematic and PCB drawings in a new Electrical folder
2023-01-20 CAD Files for Chassis
    [Base.ipt, Lid.ipt, MicroSD Module.stp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]
2023-02-06 Power Bi template update
2023-02-06 Added Chassis 3D files
    [Base Full.ipt, Base.ipt, Base.stl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]
2023-02-06 Modularized Arduino Code
2023-02-09 Added reading data from wifi and wired to GUI
    reads and displays data
2023-02-10 fixed sending data to database
    [ui_functions.py]
2023-02-11 Update to Power Bi User Interface
2023-02-11 Updated 3D files
    [3-Pin Sensor Mount.ipt, 4-Pin Sensor Mount.ipt, Back Wall.ipt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]
2023-02-11 Update CapstoneV1.pbix
    Updated version of User Interface for Power Bi
2023-02-12 REV0-01 GUI
    Fixed Time issue with SD Card and implemented error handling when device is unplugged
    [ui_functions.py]
2023-03-18 [FEAT] - Added Code Generator
    Change Log:
    -Added Arduino code generator
    -Added error handling to prevent App from crashing
    -Fixed View Dashboard button
    -Added new GUI page to add new sensors
    -Added reading the SD from the Arduino rather then taking the SD card out and plugging it into the PC
    [main.py, ui_functions.py]
2023-03-20 Updated Final Chassis Design
    [Base Chassis.ipt, Base Chassis.stl, DIN Rail Mount.ipt]
2023-03-20 Updated Arduino Code
2023-03-22 [FEAT] - Additional Error handling
    [ui_functions.py]
2023-04-01 REV1 Final Chassis
    [2-Terminal Block.step, 8-Terminal Block.step, 9V Battery.STEP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]
2023-04-01 Clean Up Repository
    [3-Pin Sensor Mount.ipt, 4-Pin Sensor Mount.ipt, Back Wall.ipt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]
2023-04-02 [SRC] - Electrical
    Added Rev1 electrical+pcb schematics
2023-04-04 [Doc] REV1 Updated Reflection
    Added Chassis Section
2023-04-08 Formulate Portable Application
    [Stocks.csv, data_x_x2_x3.csv, msft.csv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]
